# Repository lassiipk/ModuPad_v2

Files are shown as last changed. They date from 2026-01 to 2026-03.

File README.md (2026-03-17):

# ModuPad_v2

Improved Version of my ModuPad v1, With 3 Push Button rotary encoders, 25 Key switches, nice!nano MCU, and nice!view display.

---

Complete-CAD_2026-Feb-14_11-45-22AM-000_CustomizedView27695672821_png

---

## Schematic



---

## PCB

<!-- <img width="942" height="1080" alt="Screenshot 2026-01-27 120922" src="https://github.com/user-attachments/assets/e4b035c4-5acd-4f57-917d-54532f2d84d8" /> -->


---

## CAD

| Bottom | Full-CAD | Upper-Plate | 
| --- | --- | --- |
| CAD_Bottom_Fusion-Archive_2026-Feb-14_11-01-10AM-000_CustomizedView11235011731_png_alpha | Complete-CAD_2026-Feb-14_11-45-22AM-000_CustomizedView27695672821_png_alpha | CAD_Upper-Plate_Fusion-Archive_2026-Feb-14_11-26-08AM-000_CustomizedView25344388849_png_alpha |

---

## BOM

**1 USD = 279.55 PKR**

> [Cart_Images](https://github.com/lassiipk/ModuPad_v2/tree/main/BOM/Cart_Images)
>
> [BOM.csv](https://github.com/lassiipk/ModuPad_v2/blob/main/BOM/BOM.csv)
>
> [BOM Folder](https://github.com/lassiipk/ModuPad_v2/tree/main/BOM/)

| Priority | Item | Qty | Unit Price | Shipping  | Total | Notes | Ordering Site |
| --- | --- | --- | --- | --- | --- | --- | --- |
| 1 | PCB (Printed Circuit Board) |  1  | US $8.40 | US $10.30 | US $18.70 | PCB | [JCLPCB](https://github.com/lassiipk/ModuPad_v2/blob/main/BOM/Cart_Images/JLCPCB_Screenshot-2026-03-17-183200.png) | 
| 2 | 3D Printed Case |  1  | US $0.00 | US $12.00 | US $12.00 | Case / Knobs | [#printing-legion](https://hackclub.enterprise.slack.com/archives/C083P4FJM46) |
| 3 | 3.7V 800mAh Battery |  1  | US $1.79 | US $0.91  | US $2.71  | Wireless Connection | [Daraz](https://www.daraz.pk//products/i422858128-s2001359619.html?spm=a2o42.cart.0.0.af8f7d68YCkevZ&urlFlag=true) |
| 4 | nice!nano_v2.0 (NRF52840) |  1  | US $3.30 | Free | US $3.30  | MCU | [AliExpress](https://www.aliexpress.com/item/1005009516681283.html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) |
| 5 | 0.91 Inch 128x32 OLED Display |  1  | US $2.68 | Free | US $2.68  | 128x32 OLED Display | [AliExpress](https://www.aliexpress.com/item/1005008640132638.html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) |
| 6 | Cherry MX Style Switches |  1  | US $3.24 | Free | US $3.24  | Switches | [A;iExpress](https://www.aliexpress.com/item/1005010772946238.html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) |
| 7 | SK6812 MINI-E RGB LEDs |  1  | US $3.69 | Free | US $3.69  | RGB | [AliExpress](https://www.aliexpress.com/item/1005005193716172.html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) |
| 8 | EC11 Rotary Encoders |  1  | US $2.55 | Free | US $2.55  | Rotary Encoders | [AliExpress](https://www.aliexpress.com/item/1005007644083514.html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) |
| 9 | 1N4148W SMD Diodes |  1  | US $1.60 | Free | US $1.60  | 28 diodes | [AliExpress](https://www.aliexpress.com/item/1005007160563285.html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) |
| 10 | Kailh Hotswap Sockets |  1  | US $2.82 | Free | US $2.82  | Hotswap Sockets | [AliExpress](https://www.aliexpress.com/item/1005009794038277.html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) |
| 11 | DSA Keycaps |  1  | US $5.00 | Free | US $5.00  | 25 keycaps | [AliExpress](https://www.aliexpress.com/item/32842379355.html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) |
| 12 | Power Switch |  1  | US $1.95 | Free | US $1.95  | Power cutoff | [AliExpress](https://www.aliexpress.com/item/1005007372534237.html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) |
| 13 | Battery Jack |  1  | US $1.66 | Free | US $1.66  | Battery connection  | [AliExpress](https://www.aliexpress.com/item/1005004955655144.html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) |
| 14 | Reset Button |  1  | US $1.72 | Free | US $1.72  | Reset For MCU | [AliExpress](https://www.aliexpress.com/item/1005009331265393.html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) |
| 15 | 330R Resistor |  1  | US $2.27 | Free | US $2.27  | Resistor | [AliExpress](https://www.aliexpress.com/item/1005007043943146.html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) |
| 16 | 470UF Capacitor |  1  | US $2.93 | Free | US $2.93  | Capacitor | [AliExpress](https://www.aliexpress.com/item/1005008498295736.html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) |
| 17 | M2/8mm Standoffs |  1  | US $3.50 | Free | US $3.50  | Mounting | [AliExpress](https://www.aliexpress.com/item/1005008713639234.html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) |
| 18 | M2/4mm Screws |  1  | US $1.11 | Free | US $1.11  | Mounting | [AliExpress](https://www.aliexpress.com/item/1005003604942716.html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) |

---    

> **AliExpress-Total = US $40.17** | *incl. Shipping*
>
> **#Printing-Legion = US $10** | *incl. Shipping*
>
> **JLCPCB-Total = US $20.00** | *incl. Shipping*
>
> **Daraz-Total = US $2.70** | *incl. Shipping*

**Total = US $73.44** | *incl. Shipping*

---

## Timeline

**Project Started:** 05-Jan 2026 | 3:40PM

**Project Ended:** 14-Feb-2026 | 5:00 PM

**Project README Entry Written:** 17-Feb 2026 | 9:00 PM

**Project Intital Submit:** Feb 17th at 9:21 PM

**Project Second submission:** Feb 27th at N/a AM (**@alexren** requested changes, Feb 19th at 2:48 AM) BOM is optimised as much I was able to!

---

## License

This project is open‑source and intended for educational and personal use.

---

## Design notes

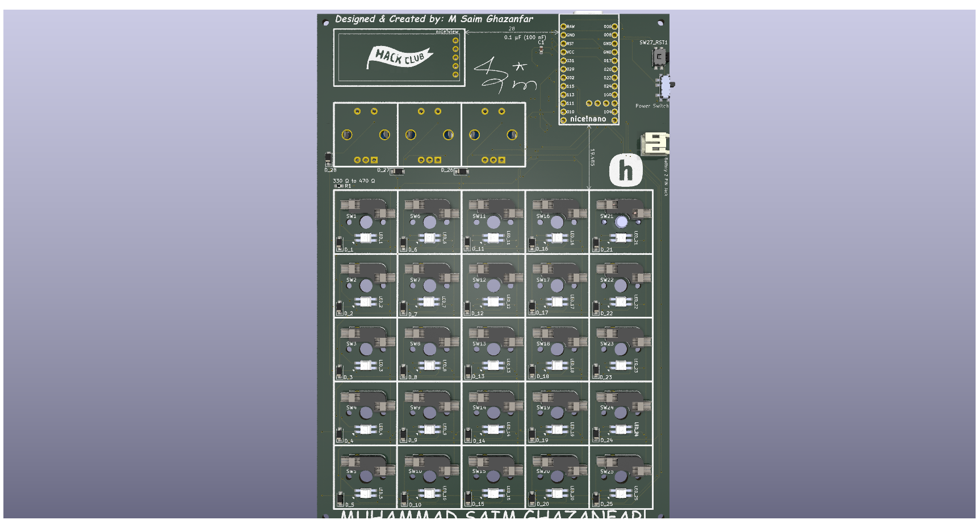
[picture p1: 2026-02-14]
Renders/KiCad/ModuPad_v2_Design_1.o/ModuPad_v2_Back.png

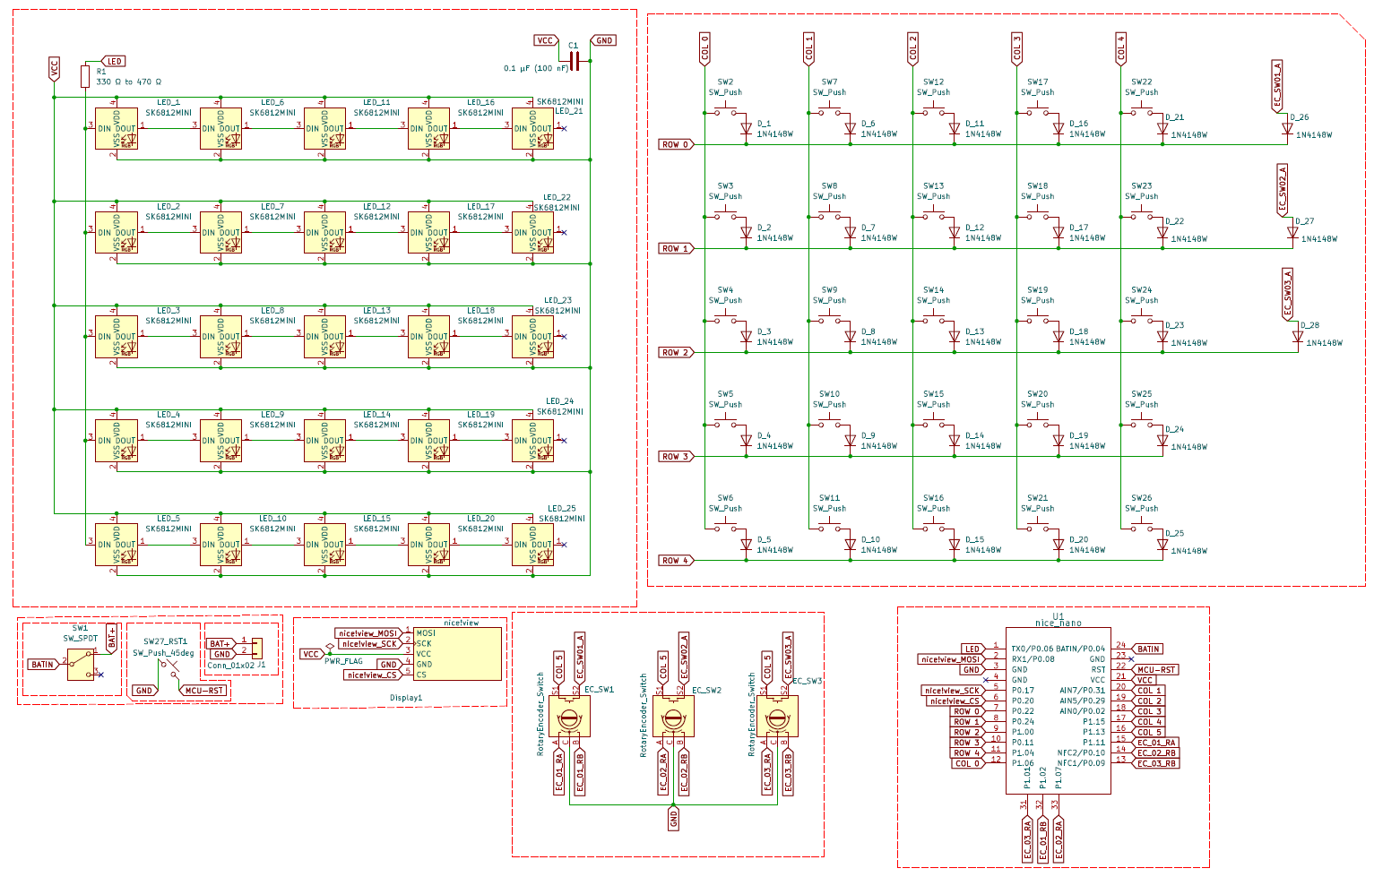
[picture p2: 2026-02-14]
Images/Schematic/Screenshot 2026-01-21 211227.png

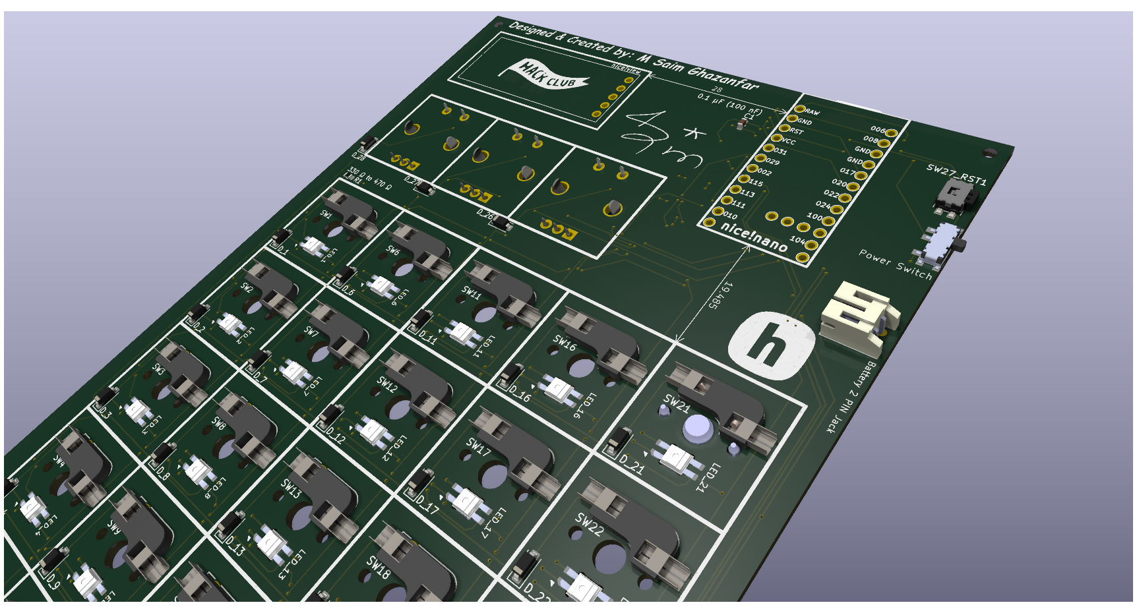
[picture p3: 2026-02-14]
Renders/KiCad/ModuPad_v2_Design_1.o/ModuPad_v2_Back-Side.png

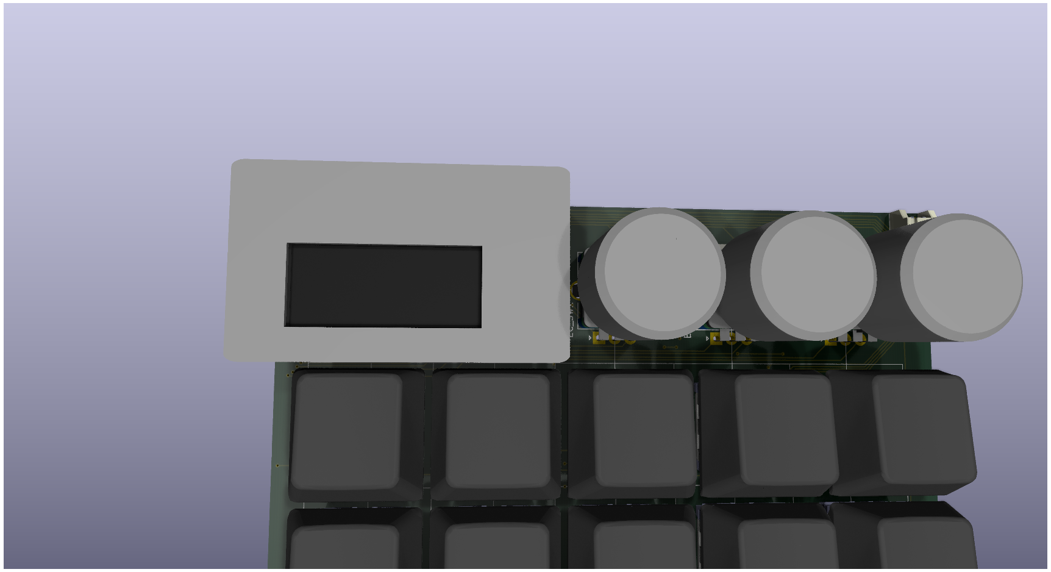
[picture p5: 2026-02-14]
Renders/KiCad/ModuPad_v2_Design_2.o/ModuPad_v2_nice!view-Cover-UpFront_2.o.png

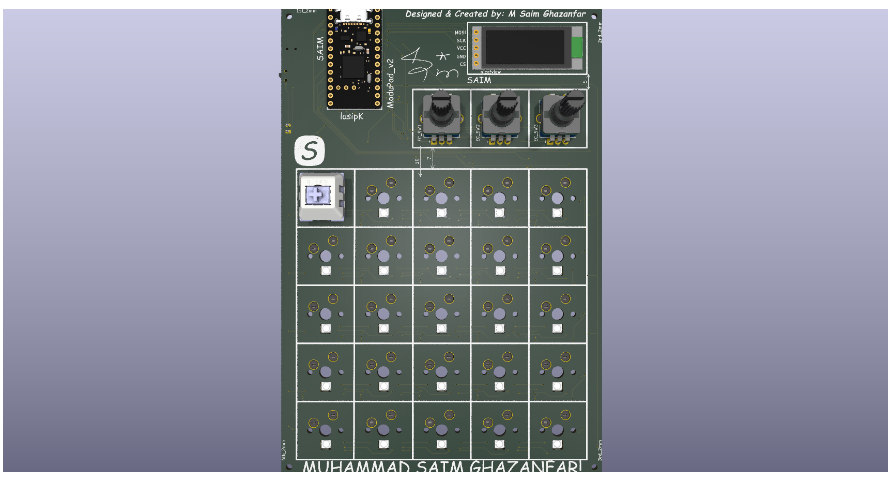
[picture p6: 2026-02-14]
Renders/KiCad/ModuPad_v2_Design_1.o/ModuPad_v2_Front.png

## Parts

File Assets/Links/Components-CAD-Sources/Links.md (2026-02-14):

0.1 [12 Pin Female Header](https://grabcad.com/library/connector-header-female-12-pins-1)
0. [5-3 Pin Femail Headers ](https://grabcad.com/library/female-header-pins-2)
1. [3-5-12 Pin Male Headers](https://grabcad.com/library/pin-header-male-2-54mm-different-pin-numbers-1)
2. [nice!view](https://grabcad.com/library/nice-view-oled-1)|
2.1 [nice!view_Display Cover](https://www.printables.com/model/1259859-corne-crkbd-display-cover/user-gcodes)
2.2 [nice!view_Cutout-Display Cover](https://www.printables.com/model/1486249-niceview-cutout-display-cover-typeractive/files)
2.3 [nice!view_lilly-Version](https://www.printables.com/model/1049833-lily58-wireless-choc-niceview-cover/files)
3. [nce!nano](https://grabcad.com/library/nice-nano-v2-1)
4. [Cherry MX Switches](https://grabcad.com/library/kailh-polia-switch-cherry-mx-compatible-1)
5. [Kailh Hotswap MX](https://grabcad.com/library/kailh-hotswap-socket-mx-pg1511-1https://grabcad.com/library/kailh-hotswap-socket-mx-pg1511-1)
6. [CHerry MX Switche KeyCap](https://grabcad.com/library/cherry-mx-keycap-1)
7. [EC11 Rotary Encoder with Switch](https://grabcad.com/library/ec11-rotary-encoder-with-switch-1)
8. [EC11 Rotary Encoder Knob](https://grabcad.com/library/knurled-encoder-knob-100)
9. [EC11 Rotary Encoder Knob_Ocreeb-12](https://github.com/sb-ocr/ocreeb-12/blob/main/STLs/Knob.stl)

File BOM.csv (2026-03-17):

Priority | Item | QTY | Unit Price | Shipping | Total | Notes | Ordering Site
1 | PCB (Printed Circuit Board) | 1 | US $8.40 | US $10.30 | US $18.70 | PCB | https://github.com/lassiipk/ModuPad_v2/blob/main/BOM/Cart_Images/JLCPCB_Screenshot-2026-03-17-183200.png
2 | 3D Printed Case | 1 | US $0.00 | US $12.00 | US $12.00 | Case / Knobs | https://hackclub.enterprise.slack.com/archives/C083P4FJM46
3 | 3.7V 800mAh Battery | 1 | US $1.79 | US $0.91 | US $2.71 | Wireless Connection | https://www.daraz.pk//products/i422858128-s2001359619.html?urlFlag=true
4 | nice!nano_v2.0 (NRF52840) | 1 | US $3.30 | Free | US $3.30 | MCU | https://www.aliexpress.com/item/1005009516681283.html?mp=1
5 | 0.91 Inch 128x32 OLED Display | 1 | US $2.68 | Free | US $2.68 | 128x32 OLED Display | https://www.aliexpress.com/item/1005008640132638.html?mp=1
6 | Cherry MX Style Switches | 1 | US $3.24 | Free | US $3.24 | Switches | https://www.aliexpress.com/item/1005010772946238.html?mp=1
7 | SK6812 MINI-E RGB LEDs | 1 | US $3.69 | Free | US $3.69 | RGB | https://www.aliexpress.com/item/1005005193716172.html?mp=1
8 | EC11 Rotary Encoders | 1 | US $2.55 | Free | US $2.55 | Rotary Encoders | https://www.aliexpress.com/item/1005007644083514.html?mp=1
9 | 1N4148W SMD Diodes | 1 | US $1.60 | Free | US $1.60 | 28 diodes | https://www.aliexpress.com/item/1005007160563285.html?mp=1
10 | Kailh Hotswap Sockets | 1 | US $2.82 | Free | US $2.82 | Hotswap Sockets | https://www.aliexpress.com/item/1005009794038277.html?mp=1
11 | DSA Keycaps | 1 | US $5.00 | Free | US $5.00 | 25 keycaps | https://www.aliexpress.com/item/32842379355.html?mp=1
12 | Power Switch | 1 | US $1.95 | Free | US $1.95 | Power cutoff | https://www.aliexpress.com/item/1005007372534237.html?mp=1
13 | Battery Jack | 1 | US $1.66 | Free | US $1.66 | Battery connection | https://www.aliexpress.com/item/1005004955655144.html?mp=1
14 | Reset Button | 1 | US $1.72 | Free | US $1.72 | Reset For MCU | https://www.aliexpress.com/item/1005009331265393.html?mp=1
15 | 330R Resistor | 1 | US $2.27 | Free | US $2.27 | Resistor | https://www.aliexpress.com/item/1005007043943146.html?mp=1
16 | 470UF Capacitor | 1 | US $2.93 | Free | US $2.93 | Capacitor | https://www.aliexpress.com/item/1005008498295736.html?mp=1
17 | M2/8mm Standoffs | 1 | US $3.50 | Free | US $3.50 | Mounting | https://www.aliexpress.com/item/1005008713639234.html?mp=1
18 | M2/4mm Screws | 1 | US $1.11 | Free | US $1.11 | Mounting | https://www.aliexpress.com/item/1005003604942716.html?mp=1
AliExpress-Total = US $40.17
#Printing-Legion = US $10
JLCPCB-Total = US $20.00
Daraz-Total = US $2.70
Total = US $73.44

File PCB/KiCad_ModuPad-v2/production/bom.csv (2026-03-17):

Designator | Footprint | Quantity | Value | LCSC Part #
BAT-POWER-SWITCH_SPDT1, LED-OLED-POWER-SWITCH_SPDT2 | SPDT_C128955 | 2 | SW_SPDT
C1 | CP_Radial_D6.3mm_P2.50mm | 1 | 0.1 µF (100 nF)
D_1, D_10, D_11, D_12, D_13, D_14, D_15, D_16, D_17, D_18, D_19, D_2, D_20, D_21, D_22, D_23, D_24, D_25, D_26, D_27, D_28, D_3, D_4, D_5, D_6, D_7, D_8, D_9 | Diode_SOD-123 | 28 | 1N4148W
EC_SW1, EC_SW2, EC_SW3 | RotaryEncoder_Alps_EC11E-Switch_Vertical_H20mm_CircularMountingHoles | 3 | RotaryEncoder_Switch
J1 | JST_PH_S2B-PH-K_02x2.00mm_Angled | 1 | Conn_01x02
J2 | OLED_128x32 | 1 | OLED_128x32
LED_1, LED_10, LED_11, LED_12, LED_13, LED_14, LED_15, LED_16, LED_17, LED_18, LED_19, LED_2, LED_20, LED_21, LED_22, LED_23, LED_24, LED_25, LED_3, LED_4, LED_5, LED_6, LED_7, LED_8, LED_9 | LED_SK6812MINI | 25 | SK6812MINI
MCU1 | nice_nano | 1 | nice!nano
R1 | R_Axial_DIN0207_L6.3mm_D2.5mm_P10.16mm_Horizontal | 1 | 330 Ω to 470 Ω
SW1, SW10, SW11, SW12, SW13, SW14, SW15, SW16, SW17, SW18, SW19, SW2, SW20, SW21, SW22, SW23, SW24, SW25, SW3, SW4, SW5, SW6, SW7, SW8, SW9 | Hotswap_MX_1.00u | 25 | SW_Push
SW27_RST1 | Panasonic_EVQPUL_EVQPUC | 1 | SW_Push_45deg

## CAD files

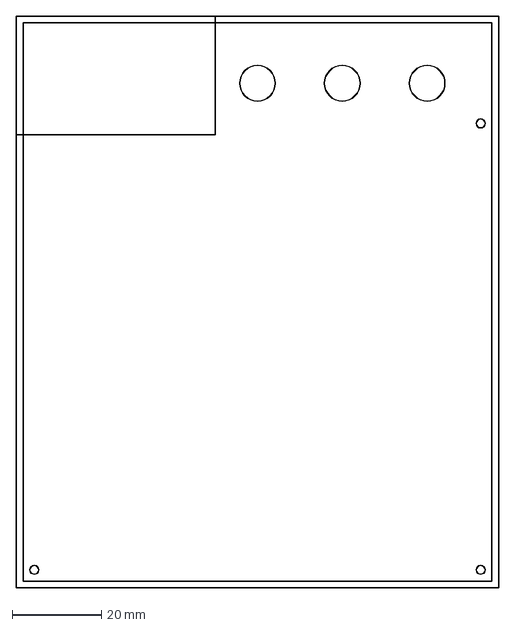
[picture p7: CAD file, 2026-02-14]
CAD/Upper-Plate/.DXF/Full-Plate_Without-Keys.dxf
108.0 x 128.0 mm

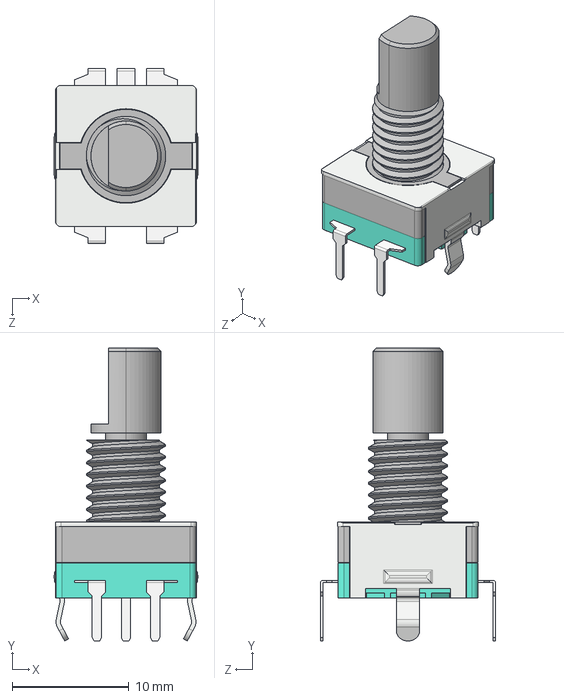
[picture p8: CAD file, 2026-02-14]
Assets/rotary-encoder-17.snapshot.2/旋转编码器.STEP
12.3 x 25.1 x 15.0 mm

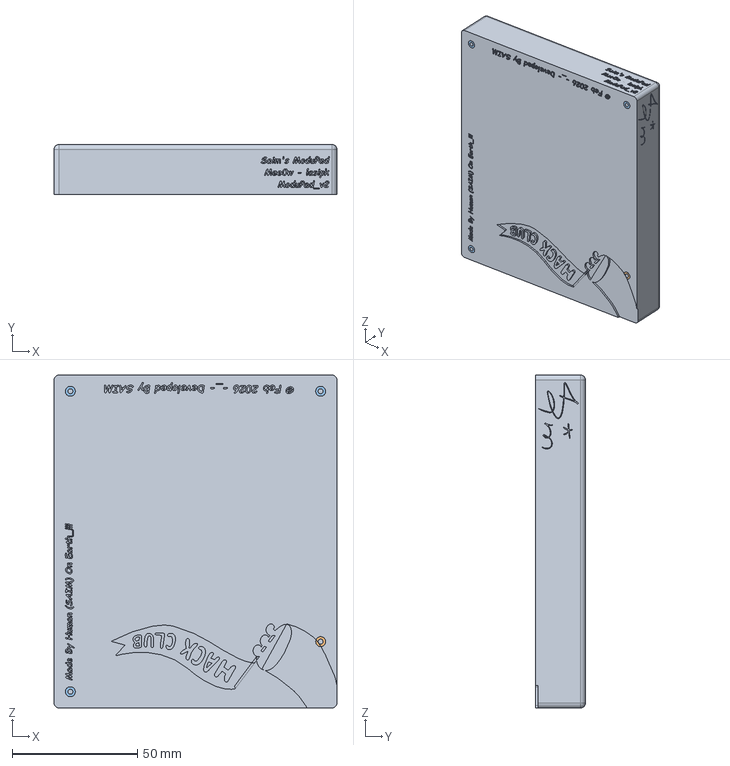
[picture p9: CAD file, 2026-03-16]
CAD/Bottom/CAD_Bottom_STEP-File.step
113.0 x 20.0 x 133.0 mm

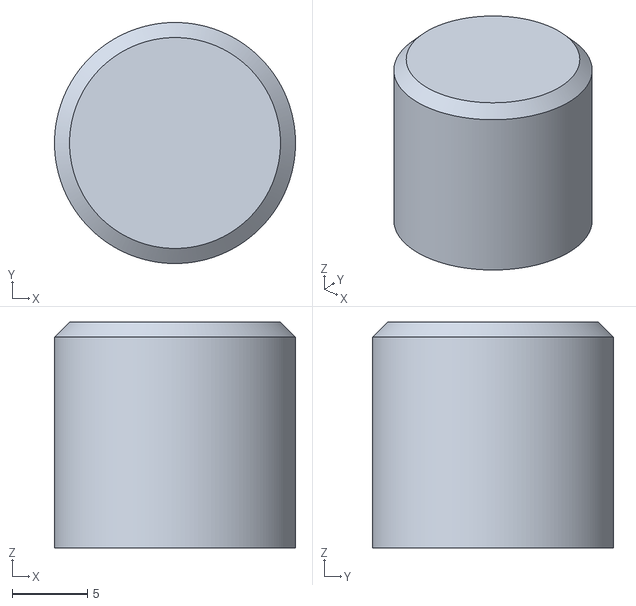
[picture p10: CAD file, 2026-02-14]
CAD/Knobs/ocreeb-12 Enocoder Knob/ocreeb_Enocoder-Knob.stl
16.0 x 16.0 x 15.0

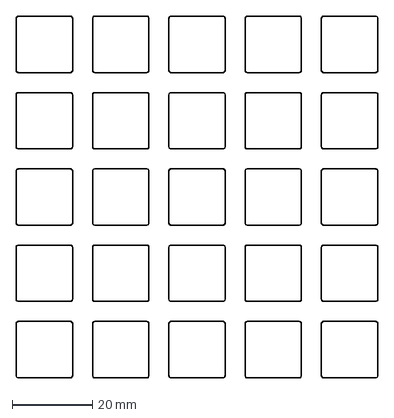
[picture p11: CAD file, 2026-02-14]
CAD/Upper-Plate/.DXF/5x5-Keys_Each_Measure-Using-KiCad.dxf
90.0 x 90.0 mm

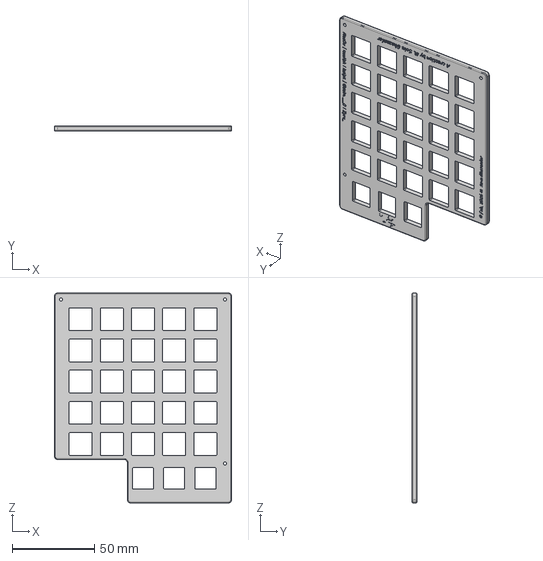
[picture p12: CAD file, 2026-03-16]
CAD/Upper-Plate/CAD_Upper_STEP-File.step
108.0 x 3.00 x 128.0 mm

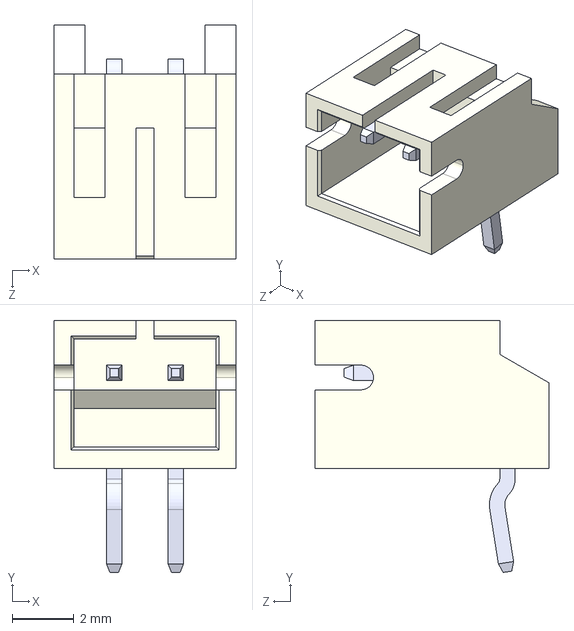
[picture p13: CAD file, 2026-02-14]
PCB/KiCad_FootPrints-3D-Models/Battery-Jack_2-Pin/S2B-PH-K-S(LF)(SN)--3DModel-STEP-1.STEP
5.90 x 8.18 x 7.60 mm

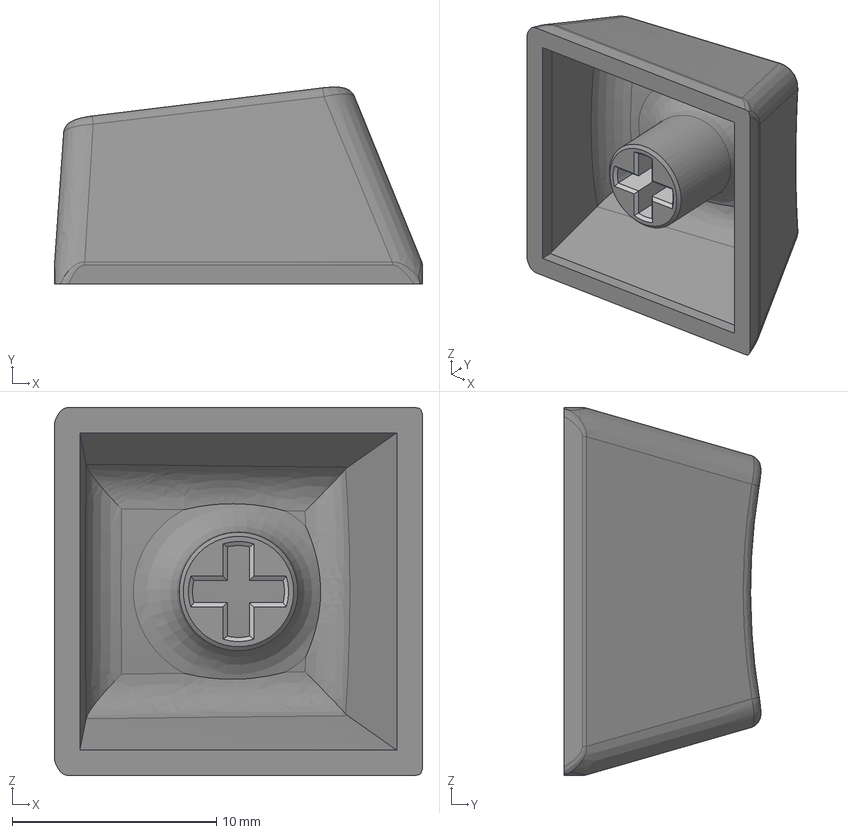
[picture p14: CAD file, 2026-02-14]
PCB/KiCad_FootPrints-3D-Models/Cherry-MX-Style/Cherry MX Keycaps/Cherry MX Keycap.stp
18.0 x 9.63 x 18.0 mm

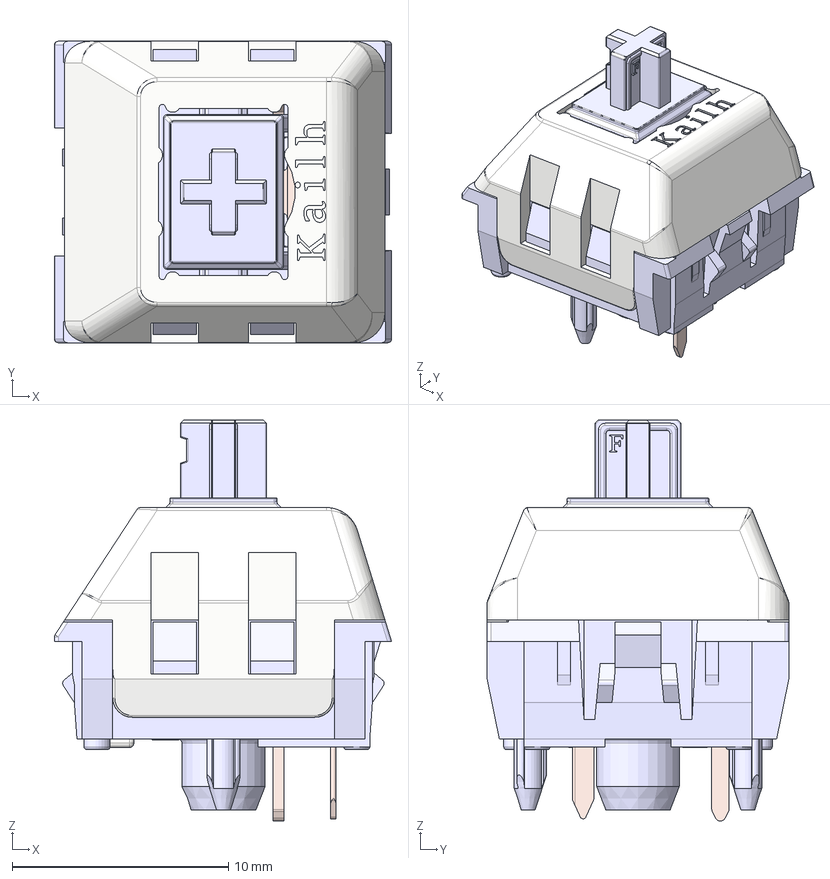
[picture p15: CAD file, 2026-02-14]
PCB/KiCad_FootPrints-3D-Models/Cherry-MX-Style/Kailh-polia-Switch-Cherry-MX-Compatible/Kailh Polia.step
15.6 x 14.0 x 18.5 mm
Housing
ThickContact
SpringContact
Stem
Lid

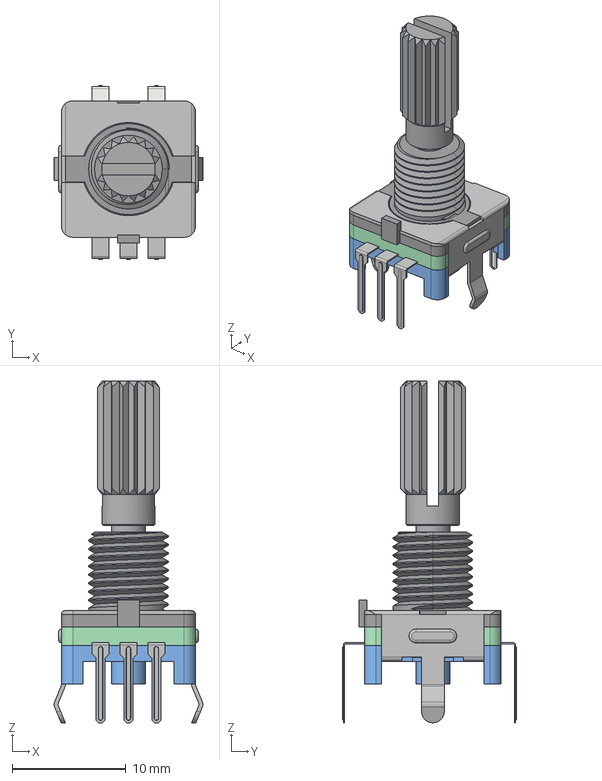
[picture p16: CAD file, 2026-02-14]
PCB/KiCad_FootPrints-3D-Models/EC11-Rotary-Encoder-With-Switch/EC11-Rotary-Encoder-Switched/EC11_Rotary_Encoder_Switched.step
13.1 x 15.3 x 30.1 mm

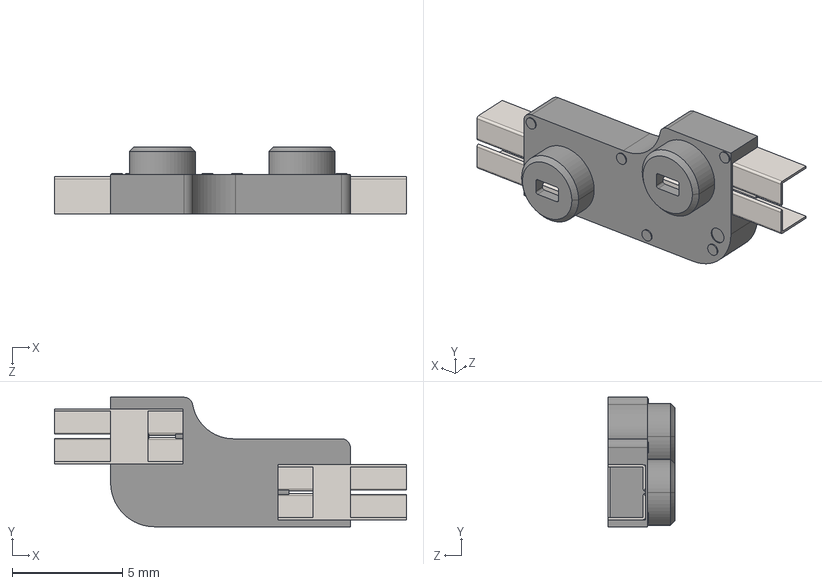
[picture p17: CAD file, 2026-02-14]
PCB/KiCad_FootPrints-3D-Models/Kailh-Hotswap-Socket-MX-PG1511/Kailh Hotswap MX.step
16.0 x 5.89 x 3.05 mm
Kailh Hotswap MX
Kailh Hotswap MX Inlay
Kailh Hotswap MX Inlay 2

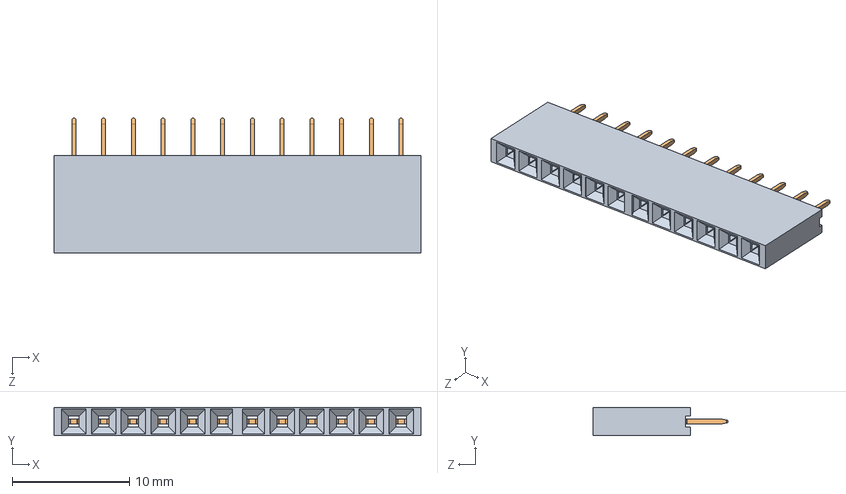
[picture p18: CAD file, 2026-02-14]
PCB/KiCad_FootPrints-3D-Models/nice!nano-v2/12-Pin-Header/HEADER_12P_FEMALE.STEP
31.3 x 2.40 x 11.5 mm
HEADER_12P_FEMALE_HOUSING
HEADER_12P_FEMALE_PIN x 12

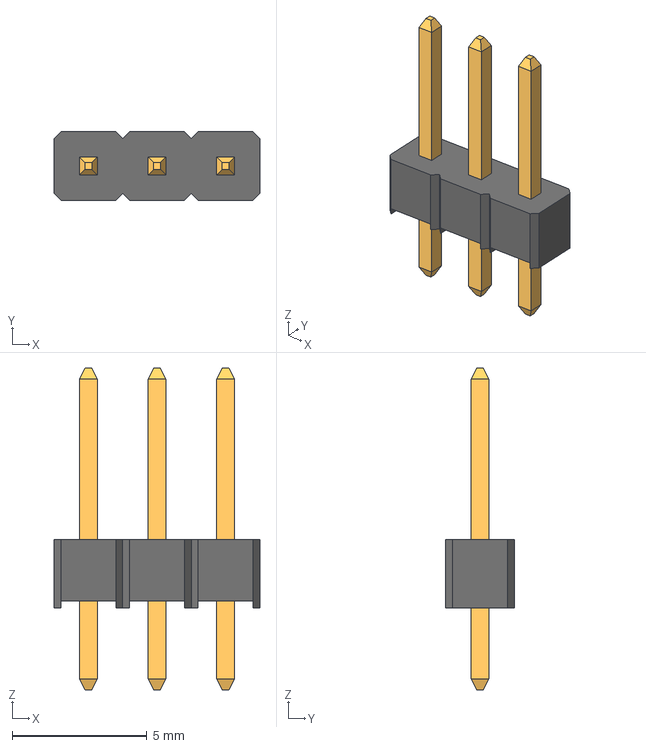
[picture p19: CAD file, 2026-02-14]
PCB/KiCad_FootPrints-3D-Models/nice!nano-v2/3-Pin-Header/3-Pin Header - Male - 2.54mm.step
7.62 x 2.54 x 11.9 mm

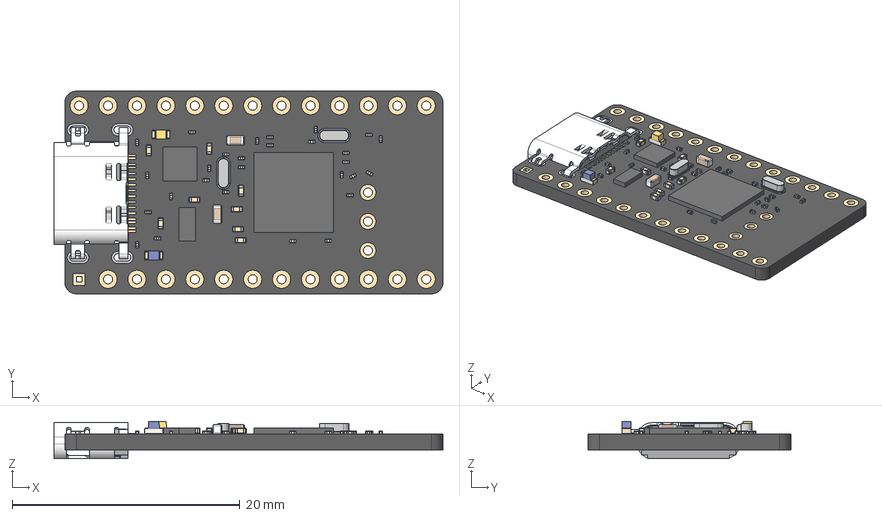
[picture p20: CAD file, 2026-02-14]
PCB/KiCad_FootPrints-3D-Models/nice!nano-v2/nice!nano v2.step
34.2 x 17.8 x 3.28 mm
nice!nano v1.0
SSOP16
LED_0603_1608Metric_ON
LED_0603_1608Metric_ON_1
Crystal Oscillator
Crystal Oscillator_1
usb4520-03-0-a_1
C0201 x 21
C0402 x 8
C0201_1 x 7

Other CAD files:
CAD/Complete CAD/Complete-CAD_Includes PCB-CAD, Bottom-CAD, & Upper-CAD.step
CAD/Knobs/Knurled Encoder Knob/EncoderKnob.step
PCB/KiCad_FootPrints-3D-Models/EC11-Rotary-Encoder-With-Switch/ocreeb-12 Enocoder Knob/Knob.stp_ap203.stp
PCB/KiCad_FootPrints-3D-Models/nice!view/5-Pin-Header/5-Pin Header - Male - 2.54mm.step
Assets/rotary-encoder-17.snapshot.2/旋转编码器.SLDPRT
CAD/Bottom/CAD_Bottom_STL-File.stl
CAD/Knobs/ocreeb-12 Enocoder Knob/Knob.stp
CAD/Knobs/ocreeb-12 Enocoder Knob/Knob.stp_ap203.stp
CAD/Old-Design/Bottom/CAD_Bottom_Fusion-Archive.f3d
CAD/Old-Design/Bottom/CAD_Bottom_STL-File.stl
CAD/Old-Design/Complete CAD/Complete-CAD_Includes PCB-CAD, Bottom-CAD, & Upper-CAD.f3d
CAD/Old-Design/Complete CAD/Complete-CAD_Includes PCB-CAD, Bottom-CAD, & Upper-CAD.step
CAD/Old-Design/Upper-Plate/.DXF/ai03 Plate Generator_5x5 Keys.dxf
CAD/Old-Design/Upper-Plate/CAD_Upper-Plate_Fusion-Archive.f3d
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

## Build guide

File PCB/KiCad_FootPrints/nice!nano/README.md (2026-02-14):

Footprint


Unofficial symbol and footprint for the nice!nano

https://nicekeyboards.com/nice-nano

The nice!nano is compatible with the elite-C (see https://deskthority.net/wiki/Elite-C for pinout), and the pro micro. The side pins will be on the same positions.

If you want pro-micro compatibility:

* Use pins RAW (positive) and GND (negative) for battery charging, don't use pins 101, 102, 107

If you want elite-C compatibility:

* Pins 101, 102, 107 should be connected to pins B7, D5, C7, F1, F0 (choose which ones).
* Pins RAW (positive) and GND (negative) should be used for battery charging

## License

This work is licensed under the GNU GPLv3.

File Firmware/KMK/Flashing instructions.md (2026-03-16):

# Flashing Instructions

---

Follow these steps to install KMK firmware on your nice!nano MCU:

1. Connect your nice!nano to your PC using a Type-C cable.
2. It will mount as a USB drive on your system.
3. Download the CircuitPython `.UF2` file for the nice!nano from:
   `https://circuitpython.org/board/nice_nano/`
4. Drag and drop the `.UF2` file onto the nice!nano drive.
   It will flash automatically, eject itself, and remount as `CIRCUITPY`.
5. Download the KMK firmware from `https://github.com/KMKfw/kmk_firmware`.
6. Copy the `kmk/` folder and your `code.py` into the root of the `CIRCUITPY` drive.
7. The MCU will execute `code.py` automatically on the next boot.
   Your keyboard should now be fully functional.

> **Note:** If the keyboard is unresponsive, double-tap the Reset button to re-enter
> bootloader mode and repeat from step 3.

---

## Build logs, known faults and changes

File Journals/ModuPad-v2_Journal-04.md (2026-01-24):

## Finished with PCB Design



Fully complete my PCB design today, PHEW that was a time sink. Had to dig through so many resources online just to get everything right, but it’s finally done. The design is completely based on the sketch from my first journal, including the 5×5 key matrix (Cherry MX style switches) with each Kilah Hotswap socket and each key having its own LED (SK6812MINI-E).

Also added 3 encoders with push buttons — no LEDs underneath them — each with a specific role: one to change the nice!view display mode, another for messing with the switch LEDs (hue, modes, etc.), and the last to interact with the OS (volume, global mute/deafen). The display (nice!view) is fully integrated for visuals, loop animations, status, and text — controllable via keys or encoders depending on user preference.

The MCU (nice!nano) is set up for flashing via ZMK for Bluetooth connectivity and all the other firmware features. Honestly, it’s wild how much can be achieved from this tiny device.

It took me over 2 days straight — I started right after finishing the schematic and didn’t even realize how much time had passed. I got so deep into the PCB that I skipped games, studies, and even meals. Crazy how focused I got.

---

## Timeline

- Start: ~6:00 PM — 21 Jan 2026
- End: 12:00 PM — 23 Jan 2026
- Journal entry written: ~12:30 PM — 23 Jan 2026

*Planned continuation: Work on the project’s CAD case, improving a lot of things for this new version, really looking forward to it.*

## Current Status

- 5×5 key matrix finalized (Cherry MX style switches, each with Kilah Hotswap socket).
- Each key has its own LED (SK6812MINI-E).
- 3 encoders with push buttons (no LEDs), each assigned specific control functions.
- Display (nice!view) fully integrated, controllable via keys and encoders.
- MCU (nice!nano) ready for ZMK flashing and Bluetooth functionality. 
- PCB layout fully matches the original sketch from the first journal.

> Next up: CAD case design. Excited to start improving this version.

## 📸 Images
| Front | Front-Side |Back-Side| Back |
|---|---|---|---|
| ModuPad_v2_Front | ModuPad_v2_Front-Side | ModuPad_v2_Back-Side | ModuPad_v2_Back |

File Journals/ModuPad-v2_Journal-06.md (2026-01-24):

# ModuPad PCB Redesign: Lessons Learned from V1

While I was measuring my PCB—component measurements, spacing between components, and overall dimensions—I noticed that the PCB measurements were not symmetric, and it would look ugly if it were not a perfect C-shape. Because of that, I decided to place all the components’ 3D models to take a closer look at the design. I have provided a render so it can be viewed as well.

After carefully reviewing and reanalyzing everything, I came to the conclusion that I will redesign the PCB again, as the current version is not very satisfying and looks quite ugly. The whole point of this project is to improve V1 and make a better version—something I was not able to achieve in my previous design.

So, here is the new plan. I will interchange the positions of the encoders and the nice!view. Currently, the nice!view is hard to see from different angles besides the front. After changing its position, it will be easier to view from other angles, such as from the key side. Previously, the three encoders were in the way, but they will not be in the next PCB design.

Next, I plan to make the entire PCB as compact as possible, because the current design occupies unnecessary desk space. It would be wasteful to have a large macropad when its purpose is to provide efficiency and modularity in a small form factor.

Tomorrow, I will start working on the new design. Right now, it is getting very late, and I need to sleep ASAP—otherwise, my mom will seize my PC and ground me for a week, and then I will not be able to continue this project at its current pace.

See you, folks.

---

## Timeline

**Start:** ~1AM — 25 Jan 2026

**End:** ~2AM — 25 Jan 2026

**Journal entry written:** ~2AM — 2026

---

ModuPad_v2_Front-Side_2 o

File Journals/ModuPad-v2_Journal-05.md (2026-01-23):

## PCB Measurements:

ModuPad_v2_Sketch-PNG-Dark-Mode_3xScale_PCB-Measurements excalidraw

---

Before starting the 3D modeling work in Autodesk Fusion 360, I sketched the PCB measurements for ModuPad_v2. The sketch is not to scale; however, all measurements are accurate and were taken directly using KiCad’s measuring tools. These measurements will be used as the foundation for the 3D modeling process in Fusion 360.

The purpose of defining these measurements early is efficiency. In the previous version of ModuPad, I did not plan ahead because I was following the HackPad blueprint-guided tutorial. In this iteration, I am creating the design from scratch, applying the knowledge gained from my first electronics and development project. I am looking forward to using these measurements to proceed with the CAD work.

## Timeline

- Start: ~5:00 PM — 23 Jan 2026
- End: ~8:40 PM — 23 Jan 2026
- Journal entry written: ~8:45 PM — 23 Jan 2026

*Planned continuation: Work on the project’s CAD case, improving a lot of things for this new version, really looking forward to it.*

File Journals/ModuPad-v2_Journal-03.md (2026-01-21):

## Finished with Schematic

Wrapped up the **schematic work** today. This session was smoother compared to the earlier one, mostly focused on cleaning things up and finalizing connections that were left open before. Everything aligned with the original plan, and the schematic now feels solid and readable without second-guessing.

It took about **4 hours** to complete after the previous journal. Next step is moving straight into PCB design using the sketch from the very first journal.

### Timeline
- **Start:** ~2:30 PM — 21 Jan 2026  
- **End:** ~6:00 PM — 21 Jan 2026  
- **Journal entry written:** ~7:30 PM  
- **Planned continuation:** PCB design session (based on initial sketch)

---

### Current Status
- 5×5 key matrix finalized.
- 3 encoders with push button added. 
- One display (nice!view)
- Each Key has its own LED (SK6812MINI-E) .  
- Single resistor at the first LED and a shared capacitor for all LEDs  
- MCU wiring clearly defined  

---

> Next is PCB. It'll be so fun.

---



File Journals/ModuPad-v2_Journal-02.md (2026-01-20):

## Unfinished Schematic — ModuPad_v2

Today’s work focused on developing the **ModuPad_v2 schematic**, which proved more challenging than expected. The primary difficulty was locating appropriate schematic symbols and matching footprints, a process that consumed significant time and required multiple revisions. Despite several setbacks and restarts, steady progress was made, and the schematic has reached a workable—though incomplete—state.

After approximately **12 hours** of concentrated effort, progress slowed due to fatigue. Work was paused intentionally to avoid errors and will resume after sleep (My mom will kill me if i dont). The schematic is still unfinished and will be continued alongside PCB work in the next session.

---

> Unfinished work is heighlietd through red rectangle.
>> I'll explain the Schematic after its fully finished. ~next-Journal

---

### Timeline
- **Start:** ~9:00 AM — 20 Jan 2026  
- **End:** ~11:55 PM — 20 Jan 2026 (work paused, not complete)  
- **Journal entry written:** ~11:40 PM  
- **Planned continuation:** ~9:00–10:00 AM — 21 Jan 2026

---

### Current Status
- Core schematic structure established  
- Symbols and footprints partially assigned  
- Further verification, cleanup, and completion required  

---



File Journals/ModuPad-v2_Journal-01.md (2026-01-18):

# ModuPad v2
ModuPad_v2_Sketch-PNG-Dark-Mode_3xScale_ excalidraw

---

>  Presenting [ModuPad v2](https://github.com/lassiipk/ModuPad_v2) improved version of [ModuPad v1](https://github.com/lassiipk/ModuPad) with 5x5 (25 keys) Macro-Focused, 3 Encoders with push buttons, nice!nano display for visuals and animations, and an nice!nano MCU for pin constraints and simplify design

---
## Planning

- The project began with a review of my [ModuPad V1](https://github.com/lassiipk/ModuPad) project, built using a Seeed XIAO RP2040, including a 3×3 key matrix, one rotary encoder, and an OLED display.
- I was planning on 4x4 key matrix, two (2) encoders, each key with addressable LEDs, and an OLED diplay, But as the project evolved I was limited and forced on using the current ModuPad features (mentioned above).
- Based on XIAO RP2040 pins, I was limited on adding more to my PAD, then i decided that the XIAO RP2040 could not realistically support the desired V2 feature set without expanders.
- Then I chose to move away from the XIAO RP2040 and select the nice!nano instead, for my [V2 ModuPad](https://github.com/lassiipk/ModuPad_v2).
- The new V2 hardware plan I proposed is as under:
  - nice!nano (MCU)
  - 5×5 key matrix (25 keys)
  - 3 encoders with push buttons
  - nice!view display
  - Addressable LEDs under each switch key
  - Hot-swap sockets
  - 1800 mAh Li-ion battery
  - Bluetooth wireless operation
 
> I decided that LEDs and the nice!view display would only be used in wired mode.
>
> Wireless mode would disable LEDs and the display to preserve battery life.

---

## Constraints

- XIAO RP2040 will not be used for V2 (limits me from adding more features into V2.
- nice!nano was chosen to reduce pin constraints and simplify design (Gives me alot of room to add more features in V2).
- V2 will use a 5×5 key matrix (Macro-Focused).
- V2 will include 3 rotary encoders with push buttons (For modularity).
- Each key will have an addressable LED for aesthetics and visuals (Because why not? LEDs are Cool Man, I love them as its make things easir when using keys in Night as the lights are off and you cant see shit! And imagin you could set cool modes that changes its Color and hue automatically).
- Hot-swap sockets will be used for all keys as it removes the hassel of sottring the key switches on the PCB, by using Hot-swap it makes things easir when cleaning and replacing a different key switch.
- nice!view will be used as the display to replace ModuPad-V1 "I²C like SSD1306" - 0.91 inc OLED Display
- A 3.7V 1800 mAh battery will be included.
- Bluetooth will be used for wireless operation (for modularity).
- LEDs and nice!view will be disabled during battery operation (to save battery power).
- LEDs and nice!view will only be active during wired (USB) operation (Again to save battery).

---

## Knowledge Gained

- Firmware is software that defines how hardware behaves and communicates with the computer.
- Mechanical switches bounce electrically when pressed.
- Debouncing filters unstable signals caused by switch bounce.
- Ghosting is caused by unintended current paths in a key matrix.
- Diodes prevent ghosting by enforcing one-way current flow.
- Key matrices reduce GPIO usage by organizing keys into rows and columns.
- Addressable LEDs require only one data pin (GPIO) regardless of LED count.
- Displays and LEDs are major contributors to power consumption (IN BATTERY/BLUETHOOT MODE).

---

## Project Status

- [ModuPad V2](https://github.com/lassiipk/ModuPad_v2) currently in planning phase.
- Architecture decisions made so far are recorded.

---

> ***I'm currently in planing phase, that can improve my fisrt project ([ModuPad](https://github.com/lassiipk/ModuPad)) in both physically and theoretically sector of the main project.
The main goal of this project ([ModuPad V2](https://github.com/lassiipk/ModuPad_v2)) is to improve my electronics and improve my [ModuPad V1](https://github.com/lassiipk/ModuPad) as much as I can, and learn electronic by building this MacroPAD from scratch with having ZERO knowlage on electronic.***

` *Everything written in this journal took me about 2-3 hours to research, learn and write it down in this jornal and log everything!* `

---

> ***Project Start Date:*** 05-JAN-2026 | 3:40_PM (After submitting MODUPAD_v1)
> ***Project Progress Status Record:*** Everything written in this Journal is the proof of what i've learnd and accomplised so far! 18-JAN-2026 | 9 PM
> ***Project Journal Submit Date:*** 18-JAN-2026 | 10 PM ( Why this much GAP between Peoject_Start_Date_ AND Project_Journal_Submit_Date ??? Answer: I was busy with other things for example: Studies. Gaming and other personal stuff!!!)

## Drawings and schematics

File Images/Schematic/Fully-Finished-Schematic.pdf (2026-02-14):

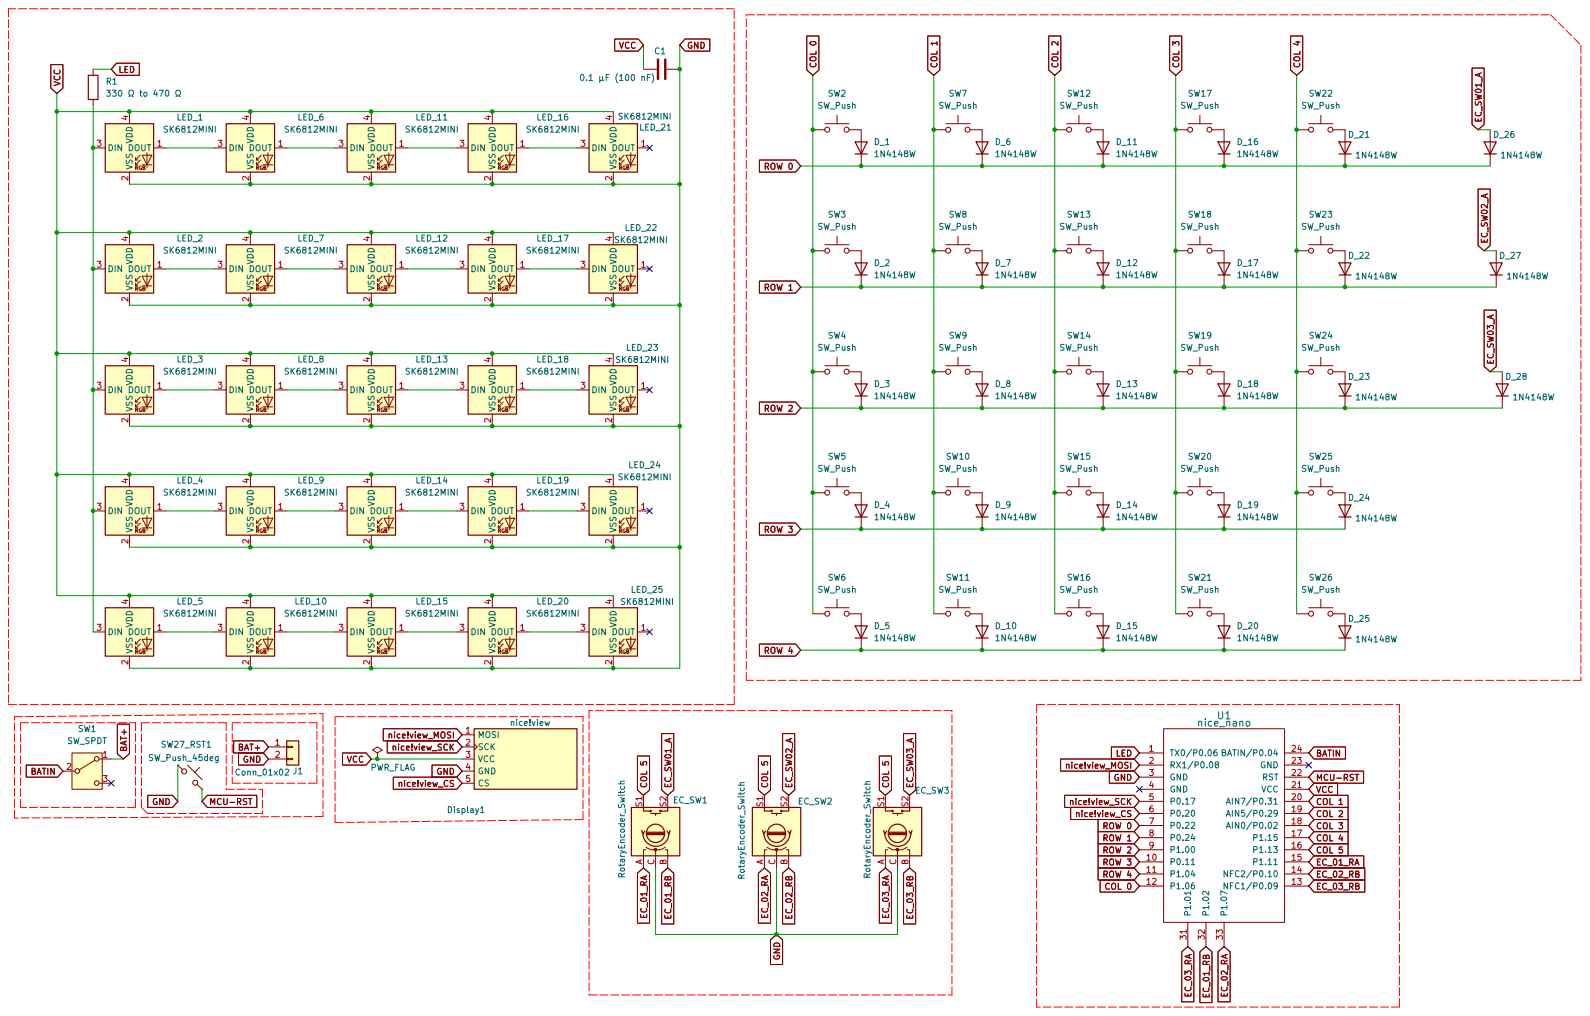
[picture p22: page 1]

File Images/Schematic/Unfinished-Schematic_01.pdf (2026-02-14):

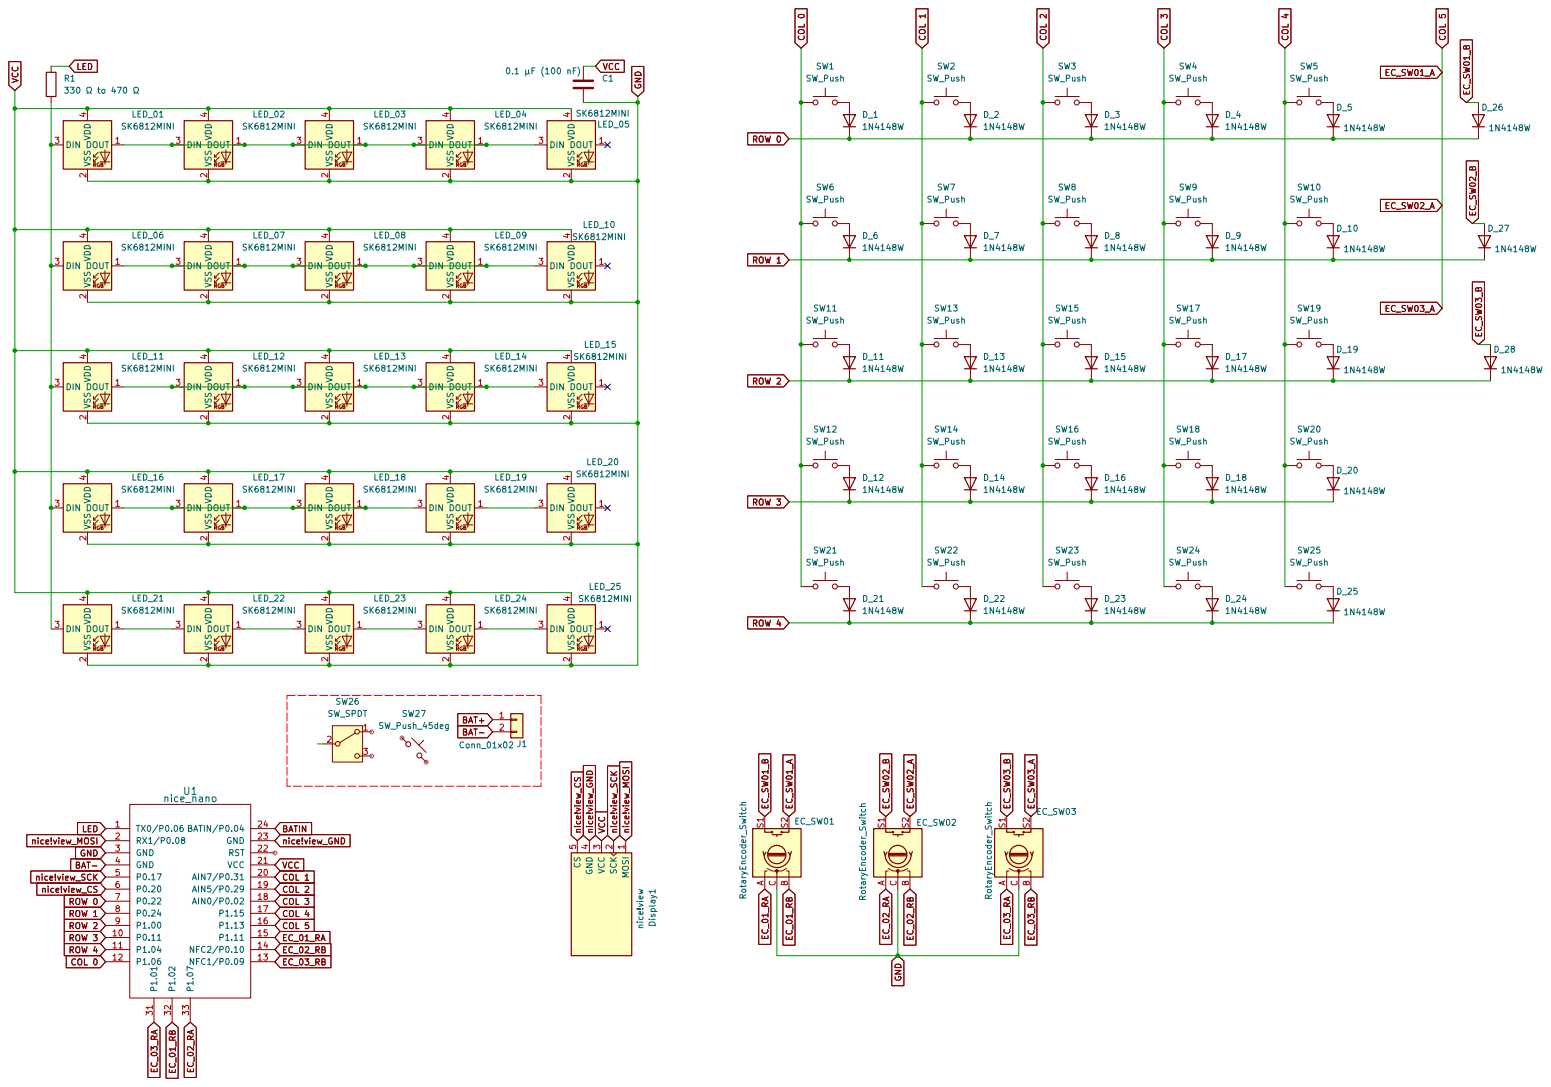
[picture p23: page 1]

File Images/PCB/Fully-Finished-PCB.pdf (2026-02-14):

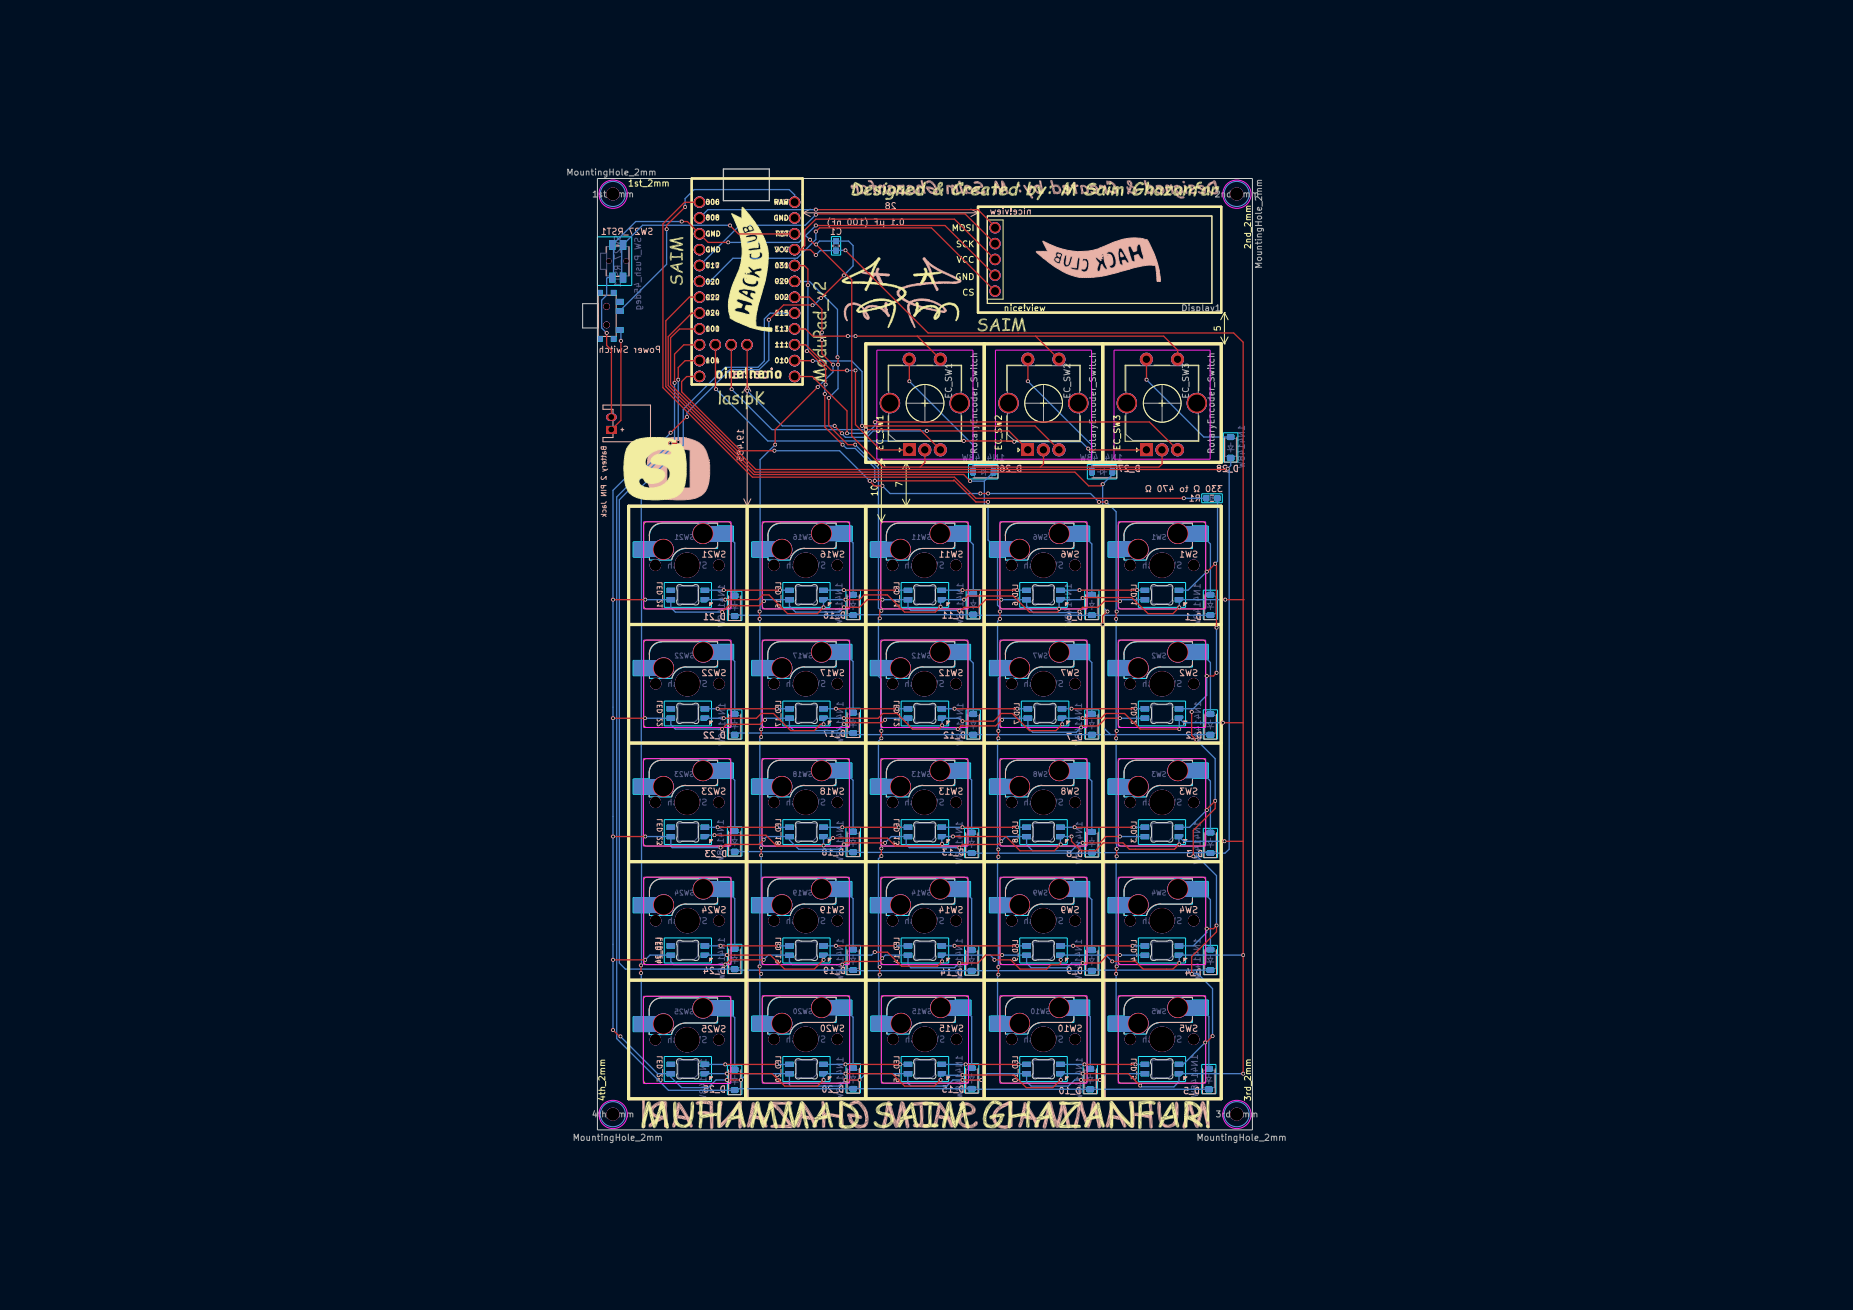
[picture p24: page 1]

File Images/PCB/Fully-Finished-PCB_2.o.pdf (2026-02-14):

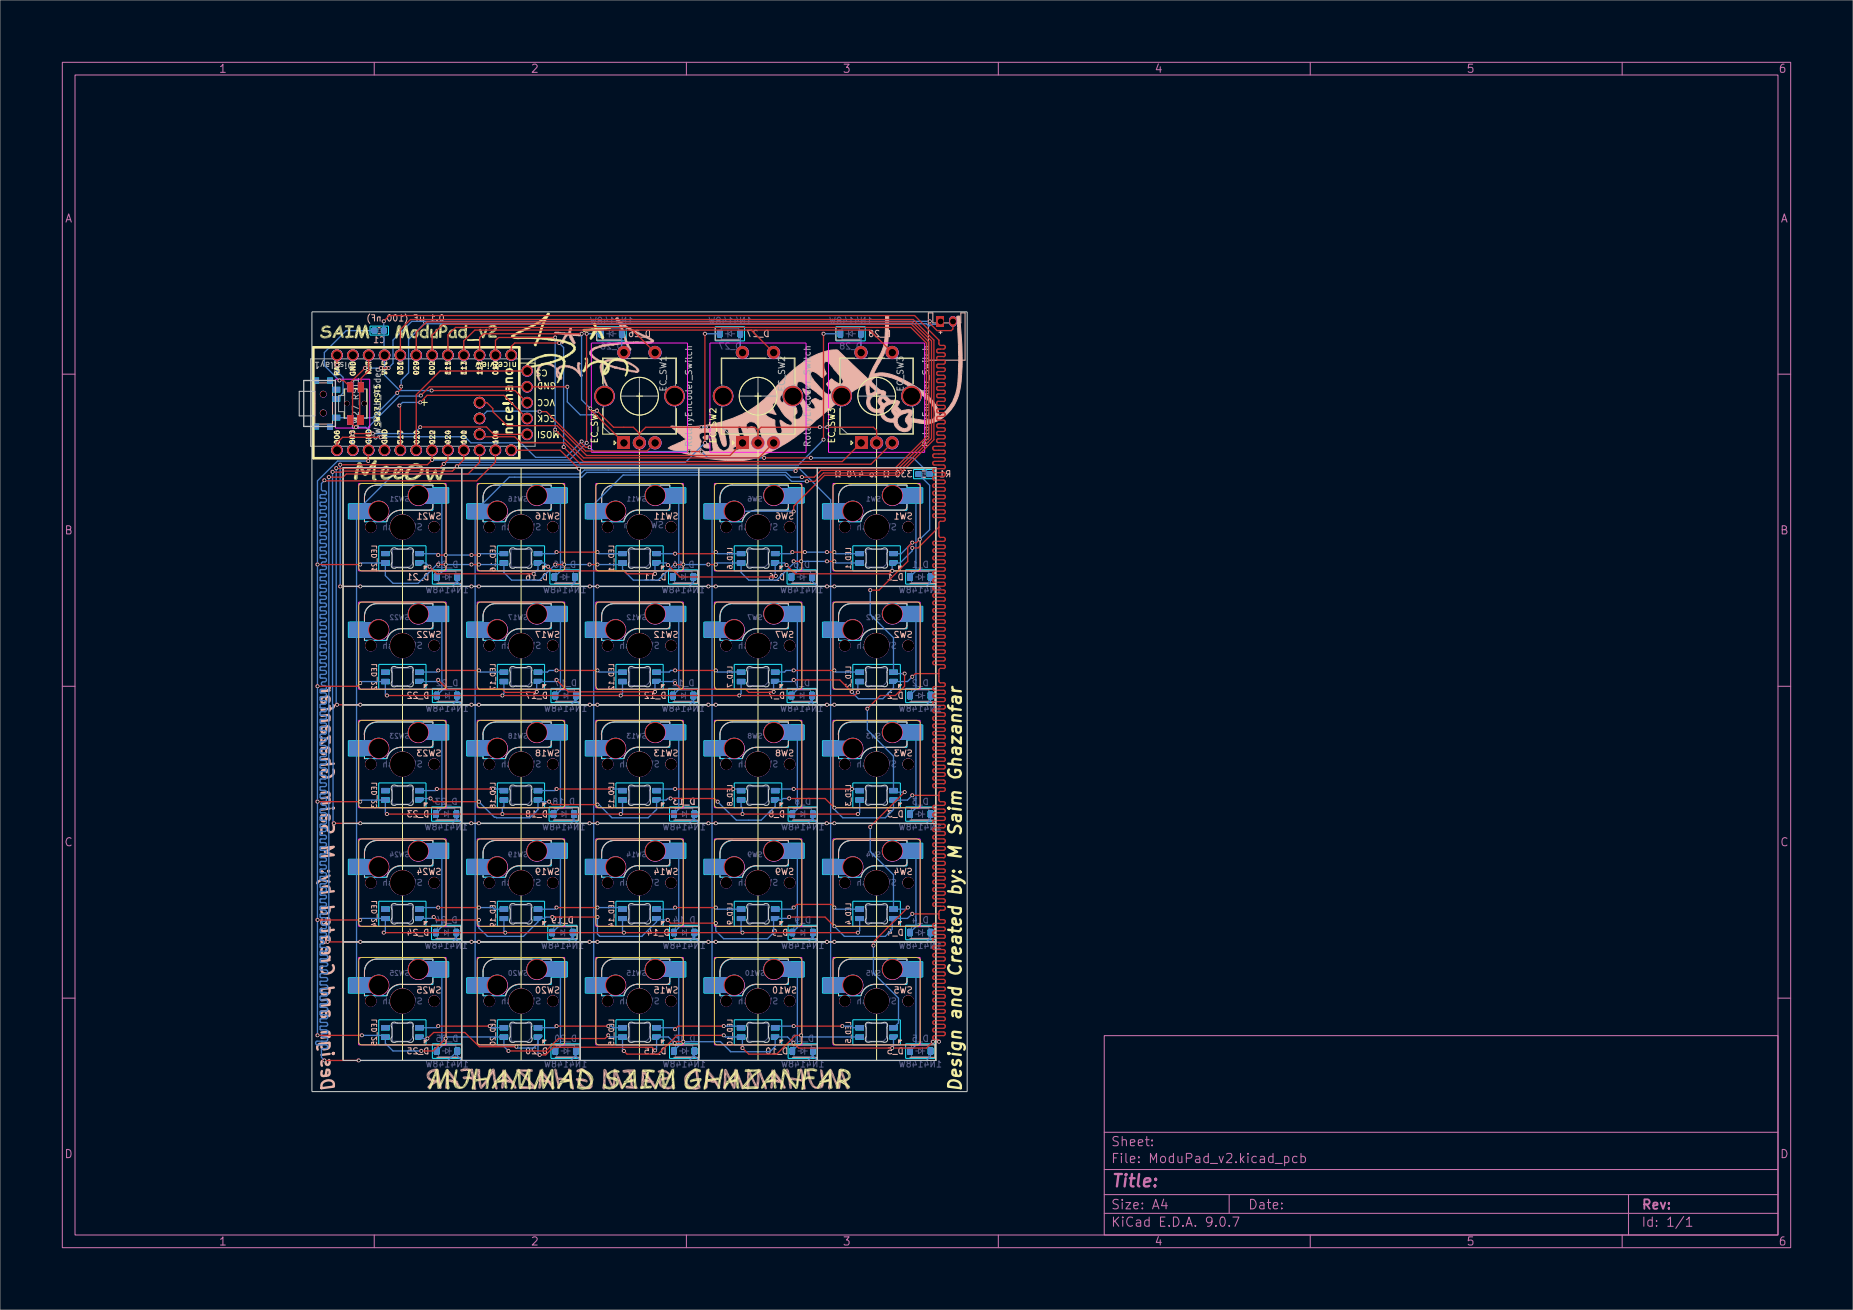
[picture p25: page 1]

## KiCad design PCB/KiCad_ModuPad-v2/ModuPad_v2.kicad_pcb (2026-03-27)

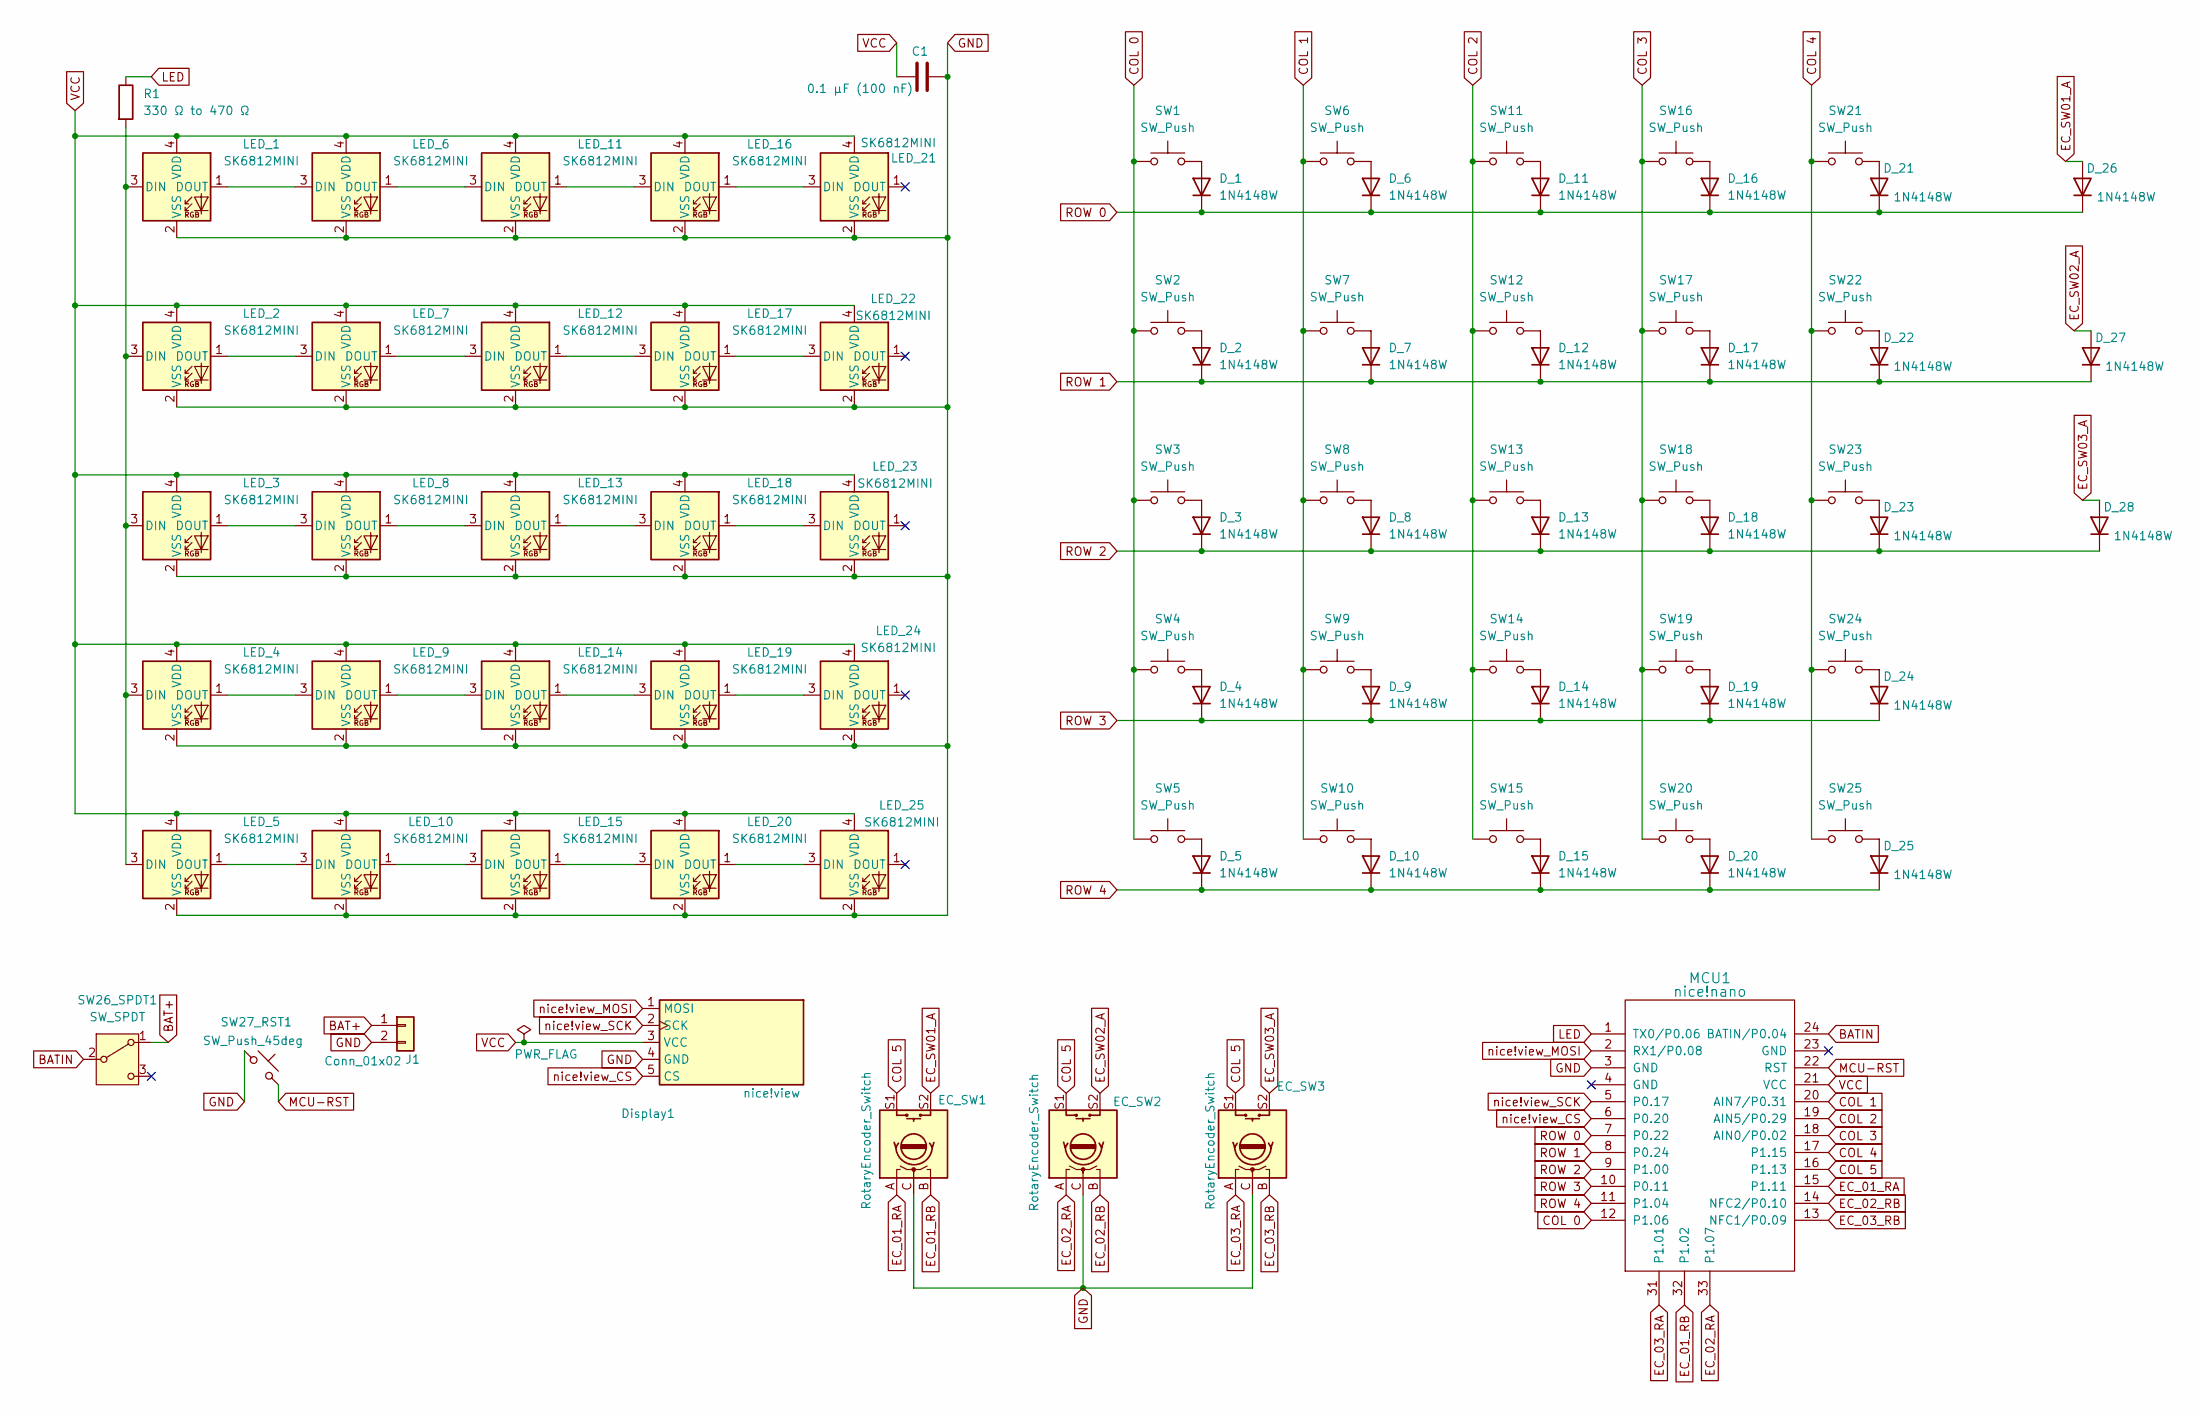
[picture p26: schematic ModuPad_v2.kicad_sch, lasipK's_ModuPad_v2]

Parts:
C1: 0.1 µF (100 nF); C_0603_1608Metric
D_1, D_2, D_3, D_4, D_5, D_6, D_7, D_8, D_9, D_10, D_11, D_12, D_13, D_14, D_15, D_16, D_17, D_18, D_19, D_20, D_21, D_22, D_23, D_24, D_25, D_26, D_27, D_28: 1N4148W; D_SOD-123
Display1: nice!view; nice_view
EC_SW1, EC_SW2, EC_SW3: RotaryEncoder_Switch; RotaryEncoder_Alps_EC11E-Switch_Vertical_H20mm_CircularMoun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
J1: Conn_01x02; JST_PH_S2B-PH-K_02x2.00mm_Angled
LED_1, LED_2, LED_3, LED_4, LED_5, LED_6, LED_7, LED_8, LED_9, LED_10, LED_11, LED_12, LED_13, LED_14, LED_15, LED_16, LED_17, LED_18, LED_19, LED_20, LED_21, LED_22, LED_23, LED_24, LED_25: SK6812MINI; SK6812MINI-E
MCU1: nice!nano; nice_nano
R1: 330 Ω to 470 Ω; R_0603_1608Metric_Pad0.98x0.95mm_HandSolder
SW1, SW2, SW3, SW4, SW5, SW6, SW7, SW8, SW9, SW10, SW11, SW12, SW13, SW14, SW15, SW16, SW17, SW18, SW19, SW20, SW21, SW22, SW23, SW24, SW25: SW_Push; SW_MX_HS_CPG151101S11_1u
SW26_SPDT1: SW_SPDT; SPDT_C128955
SW27_RST1: SW_Push_45deg; Panasonic_EVQPUL_EVQPUC

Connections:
BATIN: MCU1.24 (BATIN/P0.04), SW26_SPDT1.2 (B); also elsewhere on the board
COL 0: MCU1.12 (P1.06), SW1.1, SW2.1, SW3.1, SW4.1, SW5.1
COL 1: MCU1.20 (AIN7/P0.31), SW6.1, SW7.1, SW8.1, SW9.1, SW10.1
COL 2: MCU1.19 (AIN5/P0.29), SW11.1, SW12.1, SW13.1, SW14.1, SW15.1
COL 3: MCU1.18 (AIN0/P0.02), SW16.1, SW17.1, SW18.1, SW19.1, SW20.1
COL 4: MCU1.17 (P1.15), SW21.1, SW22.1, SW23.1, SW24.1, SW25.1
COL 5: EC_SW1.S1, EC_SW2.S1, EC_SW3.S1, MCU1.16 (P1.13)
EC_01_RA: EC_SW1.A, MCU1.15 (P1.11)
EC_01_RB: EC_SW1.B, MCU1.32 (P1.02)
EC_02_RA: EC_SW2.A, MCU1.33 (P1.07)
EC_02_RB: EC_SW2.B, MCU1.14 (NFC2/P0.10)
EC_03_RA: EC_SW3.A, MCU1.31 (P1.01)
EC_03_RB: EC_SW3.B, MCU1.13 (NFC1/P0.09)
EC_SW01_A: D_26.2 (A), EC_SW1.S2
EC_SW02_A: D_27.2 (A), EC_SW2.S2
EC_SW03_A: D_28.2 (A), EC_SW3.S2
LED: MCU1.1 (TX0/P0.06), R1.1
unnamed: D_1.2 (A), SW1.2
unnamed: D_2.2 (A), SW2.2
unnamed: D_3.2 (A), SW3.2
unnamed: D_4.2 (A), SW4.2
unnamed: D_5.2 (A), SW5.2
unnamed: D_6.2 (A), SW6.2
unnamed: D_7.2 (A), SW7.2
unnamed: D_8.2 (A), SW8.2
unnamed: D_9.2 (A), SW9.2
unnamed: D_10.2 (A), SW10.2
unnamed: D_11.2 (A), SW11.2
unnamed: D_12.2 (A), SW12.2
unnamed: D_13.2 (A), SW13.2
unnamed: D_14.2 (A), SW14.2
unnamed: D_15.2 (A), SW15.2
unnamed: D_16.2 (A), SW16.2
unnamed: D_17.2 (A), SW17.2
unnamed: D_18.2 (A), SW18.2
unnamed: D_19.2 (A), SW19.2
unnamed: D_20.2 (A), SW20.2
unnamed: D_21.2 (A), SW21.2
unnamed: D_22.2 (A), SW22.2
unnamed: D_23.2 (A), SW23.2
unnamed: D_24.2 (A), SW24.2
unnamed: D_25.2 (A), SW25.2
unnamed: Display1.1 (MOSI), MCU1.2 (RX1/P0.08)
unnamed: LED_1.3 (DIN), LED_2.3 (DIN), LED_3.3 (DIN), LED_4.3 (DIN), LED_5.3 (DIN), R1.2
unnamed: LED_1.1 (DOUT), LED_6.3 (DIN)
unnamed: LED_2.1 (DOUT), LED_7.3 (DIN)
unnamed: LED_3.1 (DOUT), LED_8.3 (DIN)
unnamed: LED_4.1 (DOUT), LED_9.3 (DIN)
unnamed: LED_5.1 (DOUT), LED_10.3 (DIN)
unnamed: LED_10.1 (DOUT), LED_15.3 (DIN)
unnamed: LED_6.1 (DOUT), LED_11.3 (DIN)
unnamed: LED_11.1 (DOUT), LED_16.3 (DIN)
unnamed: LED_7.1 (DOUT), LED_12.3 (DIN)
unnamed: LED_12.1 (DOUT), LED_17.3 (DIN)
unnamed: LED_8.1 (DOUT), LED_13.3 (DIN)
unnamed: LED_13.1 (DOUT), LED_18.3 (DIN)
unnamed: LED_9.1 (DOUT), LED_14.3 (DIN)
unnamed: LED_14.1 (DOUT), LED_19.3 (DIN)
unnamed: LED_15.1 (DOUT), LED_20.3 (DIN)
unnamed: LED_16.1 (DOUT), LED_21.3 (DIN)
unnamed: LED_17.1 (DOUT), LED_22.3 (DIN)
unnamed: LED_18.1 (DOUT), LED_23.3 (DIN)
unnamed: LED_19.1 (DOUT), LED_24.3 (DIN)
unnamed: LED_20.1 (DOUT), LED_25.3 (DIN)
ROW 0: D_1.1 (K), D_6.1 (K), D_11.1 (K), D_16.1 (K), D_21.1 (K), D_26.1 (K), MCU1.7 (P0.22)
ROW 1: D_2.1 (K), D_7.1 (K), D_12.1 (K), D_17.1 (K), D_22.1 (K), D_27.1 (K), MCU1.8 (P0.24)
ROW 2: D_3.1 (K), D_8.1 (K), D_13.1 (K), D_18.1 (K), D_23.1 (K), D_28.1 (K), MCU1.9 (P1.00)
ROW 3: D_4.1 (K), D_9.1 (K), D_14.1 (K), D_19.1 (K), D_24.1 (K), MCU1.10 (P0.11)
ROW 4: D_5.1 (K), D_10.1 (K), D_15.1 (K), D_20.1 (K), D_25.1 (K), MCU1.11 (P1.04)
RST: MCU1.22 (RST), SW27_RST1.2
SCL: Display1.5 (CS), MCU1.6 (P0.20); also elsewhere on the board
SDA: Display1.2 (SCK), MCU1.5 (P0.17); also elsewhere on the board

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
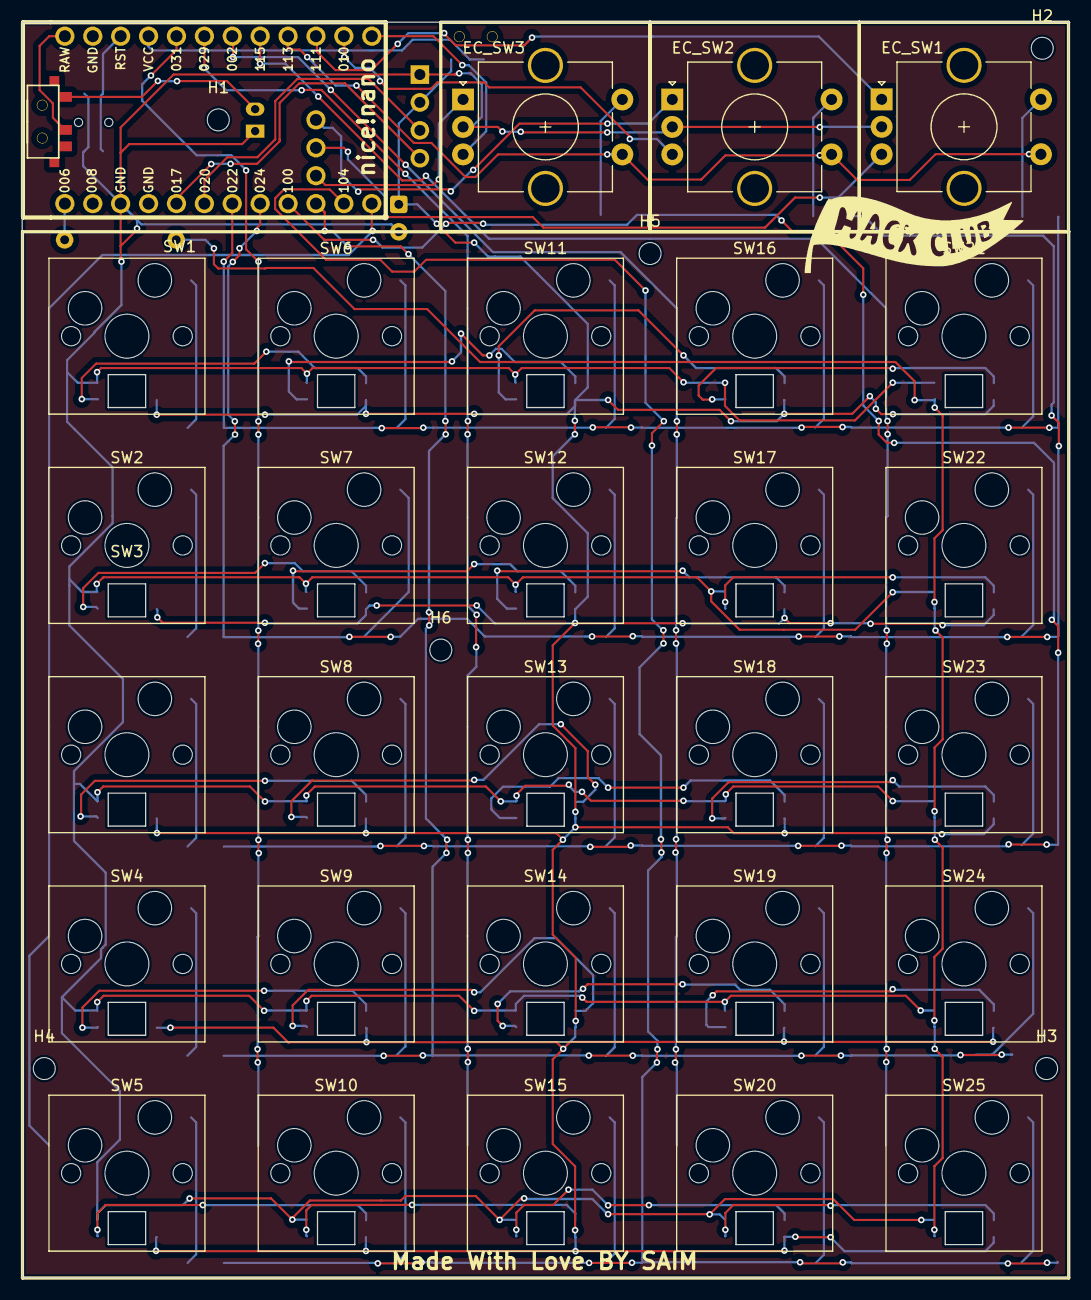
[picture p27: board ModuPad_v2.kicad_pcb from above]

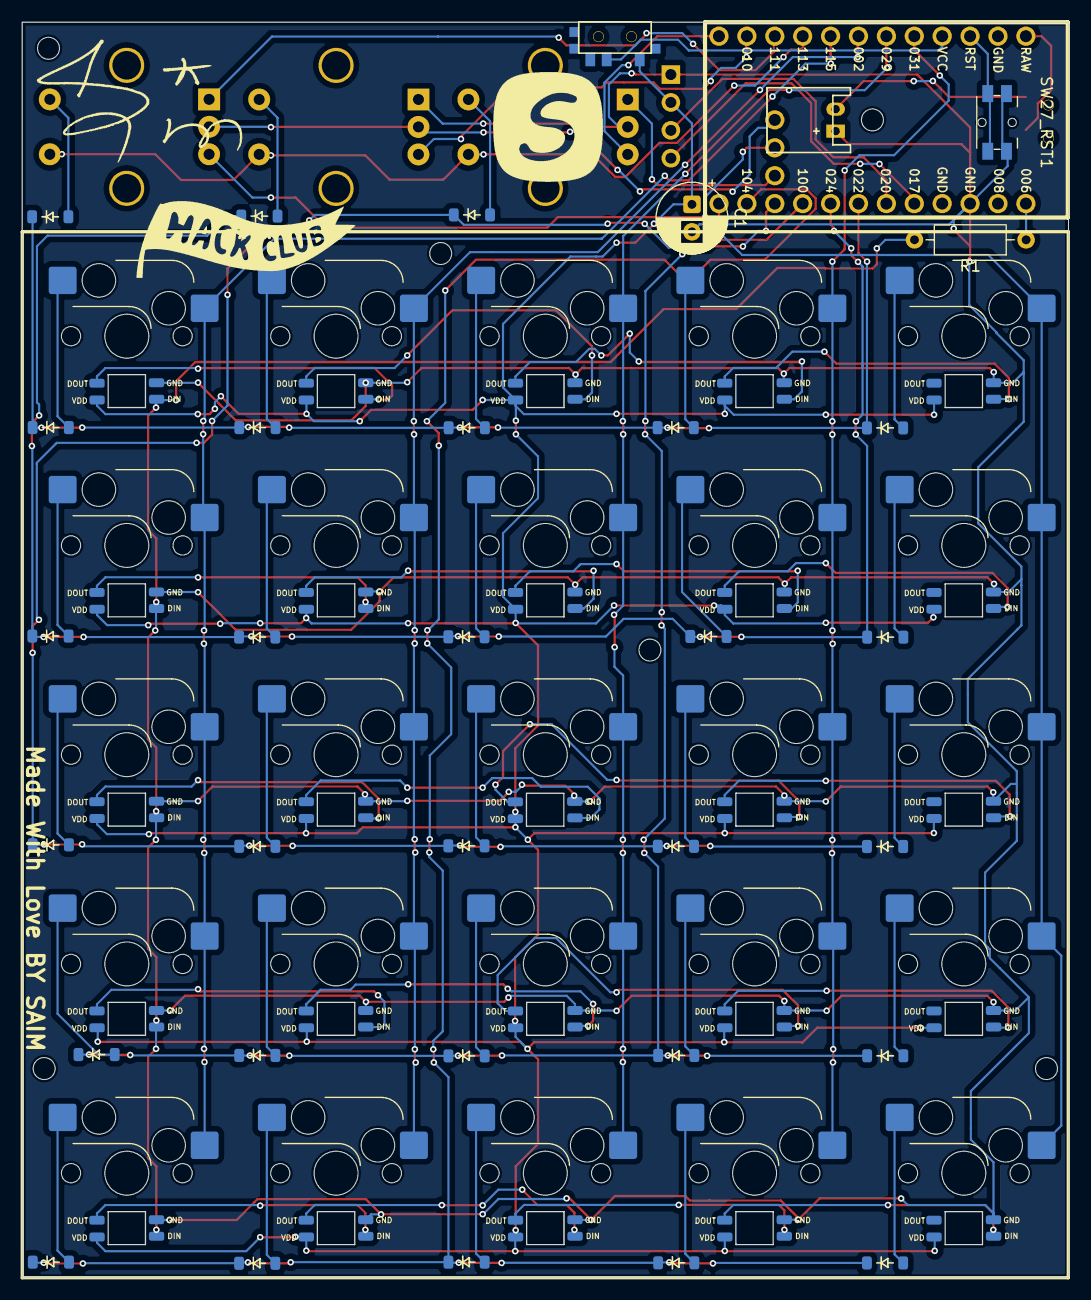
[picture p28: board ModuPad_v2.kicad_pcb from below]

Board: 2 copper layers, 95.3 x 114.3 mm, 95 parts (32 on the bottom side), 75 nets.

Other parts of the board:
BAT-Power-Switch_SPDT1: SW_SPDT; SPDT_C128955
H1, H2, H3, H4, H5, H6: MountingHole; MountingHole_2mm
J2: OLED_128x32
LED-OLED-Power-Switch_SPDT2: SW_SPDT; SPDT_C128955

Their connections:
BATIN: BAT-Power-Switch_SPDT1.2 (B); also elsewhere on the board
SCL: J2.3 (SCL); also elsewhere on the board
SDA: J2.4 (SDA); also elsewhere on the board

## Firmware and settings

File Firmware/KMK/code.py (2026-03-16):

print("Mee0w from ModuPad_v2!")
print("Launching Mee0w... inthe KMK world!")

import board

from kmk.kmk_keyboard import KMKKeyboard
from kmk.keys import KC
from kmk.scanners import DiodeOrientation
from kmk.extensions.display import Display, TextEntry, ImageEntry
from kmk.modules.encoder import EncoderHandler
from kmk.extensions.media_keys import MediaKeys
from kmk.extensions.display.ssd1306 import SSD1306
import busio

#-----------------------------------------------------------------------------------

keyboard = KMKKeyboard()

# ==============================
#Switch setup
# ==============================

keyboard.col_pins = (board.D9, board.D15, board.D18, board.D19 board.D21)
keyboard.row_pins = (board.D4, board.D5, board.D6, board.D7, board.D8)
keyboard.diode_orientation = DiodeOrientation.COL2ROW

# 5x5 matrix

keyboard.keymap = [

    [KC.N1,  KC.N2,  KC.N3,  KC.N4,  KC.N5,
     KC.N6,  KC.N7,  KC.N8,  KC.N9,  KC.N10,
     KC.N11, KC.N12, KC.N13, KC.N14, KC.N15,
     KC.N16, KC.N17, KC.N18, KC.N19, KC.N20,
     KC.N21, KC.N22, KC.N23, KC.N24, KC.N25],      
    
    ],

#------------------------------------------------------------------------------------

# ==============================
# Encoder
# ==============================

encoder_handler = EncoderHandler()

# Regular GPIO Encoder Pins assigned as D-Pins, with no button and 2 steps per detent. 

encoder_handler.pins = ( (board.D6, board.D7, None, False, 2), ) 
keyboard.modules.append(encoder_handler)

# You can optionally predefine combo keys as for your layout, but you can also just use the encoder as a regular encoder and it will send the keycodes in the order defined in the map.

keyboard.extensions.append(MediaKeys())

# You can also use the encoder as a rotary switch by changing KC's To other Keycode, for exaample KC.A n B, and it will send the keycode on each step, Just like With Keyswitches.
encoder_handler.map = [ ((KC.AUDIO_VOL_UP, KC.AUDIO_VOL_DOWN, KC.NO),), # Standard
                        #((KC.VOLD, KC.VOLU, KC.NO),), # Extra
                        #((KC.A, KC.Z, KC.N1),), # NumPad not yet properly configured
                        #((KC.A, KC.Z, KC.N1),), # Gaming not yet properly configured

                        ]                      

#------------------------------------------------------------------------------------

# ==============================
#Display setup
# ==============================

# I2C setup
i2c = busio.I2C(board.D3, board.D2)

# Driver FIRST
driver = SSD1306(
    i2c=i2c,
    device_address=0x3C,
)

# Then Display

display = Display(
    display=driver,
    entries=[

        #TextEntry(text="Made with ♥ by SAIM", x=0, y=0, inverted=True, layer=0   ),
        #TextEntry(text="Is't it Cool???? Huh?", x=0, y=16, inverted=True, layer=0 ),

        ImageEntry(
            
            image="1.bmp"#, x=0, y=0
        
        ),    
           
        ],

    width=128,
    height=32,
    flip = True, # flips your display content
    #flip_left = False, # flips your display content on left side split
    #flip_right = True, # flips your display content on right side split
    #brightness=0.8, # initial screen brightness level
    #brightness_step=0.1, # used for brightness increase/decrease keycodes
    dim_time=15, # time in seconds to reduce screen brightness
    dim_target=0.1, # set level for brightness decrease
    off_time=30, # time in seconds to turn off screen
    #powersave_dim_time=10, # time in seconds to reduce screen brightness
    #powersave_dim_target=0.1, # set level for brightness decrease
    #powersave_off_time=30, # time in seconds to turn off screen

)

keyboard.extensions.append(display)

#------------------------------------------------------------------------------------

#RGB SEtup

# Frest LED DIN pin is connected at D! pin of MCU. and there are total of 25 Pin connected paralelly to each other.
#------------------------------------------------------------------------------------

if __name__ == '__main__':
    keyboard.go()

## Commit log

2026-02-14 Project Uploded
    [12-Pin Header - Male - 2.54mm.step, 3-Pin Header - Male - 2.54mm.step, 5-Pin Header - Male - 2.54mm.step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]
2026-02-14 Deleted unnessorry gerber files
    [ModuPad_v2-B_Adhesive.gbr, ModuPad_v2-B_Courtyard.gbr, ModuPad_v2-B_Cu.gbr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]
2026-02-15 Add Gerber files for ModuPad v2 PCB
    Add Gerber outputs for the ModuPad_v2 KiCad project to PCB/KiCad_ModuPad-v2/Gerber. Files include an archive (Gerber.rar) on 2026-02-15 for PCB fabrication.
    [ModuPad_v2-B_Cu.gbl, ModuPad_v2-B_Mask.gbs, ModuPad_v2-B_Paste.gbp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]
2026-02-15 Split and reformat BOM into PKR and USD files
2026-02-15 Remove BOM markdown files
    Delete BOM/BOM.md, BOM/BOM_PKR.md, and BOM/BOM_USD.md which contained bill-of-materials for the mechanical keyboard build. Clean up repository by removing redundant or outdated BOM documents.
2026-02-15 Add BOM files for mechanical keyboard build
    Add Bill of Materials for the mechanical keyboard project: BOM/BOM.md (combined PKR & USD lists) and separate BOM/BOM_PKR.md and BOM/BOM_USD.md. Each file enumerates components, quantities, unit pric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
2026-02-17 Replace BOM with markdown variants and add assets
    Remove legacy BOM files and add structured BOM Markdown files (PKR, USD, combined PKR+USD) and a links file. Add BOM/cart screenshots and a BOM image, plus CAD knob assets (RAR, renamed STEP/STL) and a Gerber ZIP for KiCad ModuPad-v2. Also remove old BOM.md, BOM_PKR.md, and BOM_USD.md to consolidate documentation into the BOM_Markdown folder.
    [Knurled_Encoder-Knob.step, ocreeb_Enocoder-Knob.stl]
2026-02-17 Update README with project details and images
    Added detailed project information including schematic, PCB, CAD, BOM, timeline, and license.
2026-02-26 Consolidate BOM into single file
2026-02-26 Revise BOM pricing and update timeline
2026-03-05 Add flashing instructions.md and removed unnecessary PCB files.
    [ModuPad_v2_Old-Design.kicad_pcb]
2026-03-05 Create BOM.csv inside BOM Folder
    [BOM.csv]
2026-03-10 Update BOM and PCB
    [478CKS010M.step, BOM.csv, MFR-25FBF52-1K.step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]
2026-03-17 Bom Update
2026-03-17 Update BOM
2026-05-21 Moved Old-Design to /Old-Design Folder
    Moved Old-Design to /Old-Design Folder, Because The PCB is Redesigned, The Measurements are Changed.
    [5x5-Keys_Each_Measure-Using-KiCad.dxf, CAD_Bottom_Fusion-Archive.f3d, CAD_Bottom_STEP-File.step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]
